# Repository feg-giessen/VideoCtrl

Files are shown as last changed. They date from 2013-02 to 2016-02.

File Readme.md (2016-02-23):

# VideoController

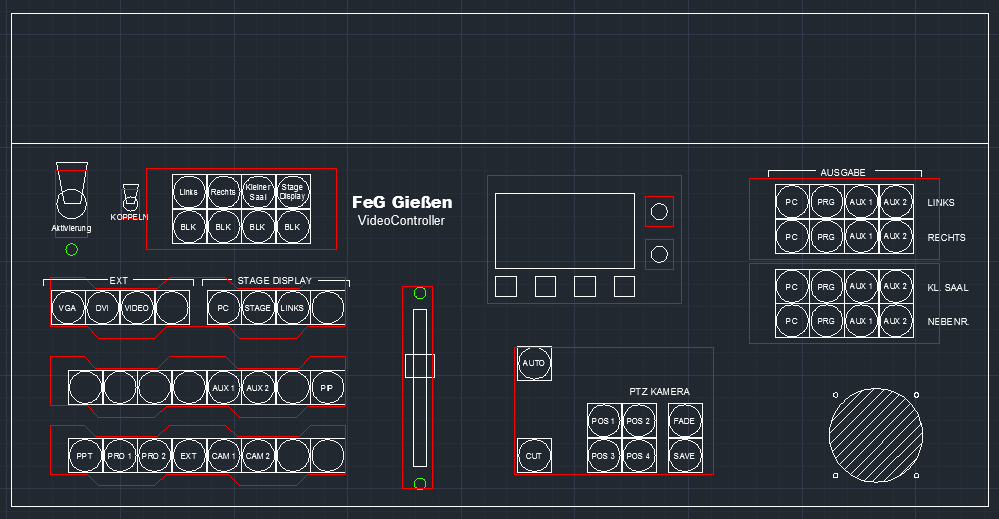
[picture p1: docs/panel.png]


Some more photos: https://www.flickr.com/photos/peschuster/tags/videoctrl/










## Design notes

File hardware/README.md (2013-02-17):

# Hardware Files #

- schematics
- part lists
- board layouts

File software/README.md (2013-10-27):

# Software Files #

- firmware
- etc.

# Development Environment 

- IDE: Eclipse Helios
- Eclipse plugins for ChibiOS: (copy to `/plugins` directory)
 - org.chibios.tools.eclipse.config_1.2.1.jar
 - org.chibios.tools.eclipse.debug_1.0.8.jar
- Compiler: arm-none-eabi (v4.7 - https://launchpad.net/gcc-arm-embedded/+download) 
- binutils (make, etc.): msys 1.0 (MinGW)

## Batch files

Start Eclipse (example):

    SET PATH=C:\Windows\system32;C:\Windows;C:\Windows\System32\Wbem;H:\Elektronik\bin-tools;H:\Elektronik\bin-tools\arm-none-eabi\bin;H:\Elektronik\MinGw\msys\1.0\bin
    
    @pushd %~dp0
    start OlimexOds\eclipse\eclipse.exe

Start OpenOCD (example):

    cd H:\Elektronik\VideoCtrl\software\firmware\VideoCtrl
    
    \Elektronik\OlimexODS\openocd-0.6.1\bin-x64\openocd-x64-0.6.1.exe -f \Elektronik\OlimexODS\openocd-0.6.1\scripts\interface\olimex-arm-usb-tiny-h.cfg -f project.cfg 

## Debug Configuration

### Init

    target remote localhost:3333
    monitor reset halt
    monitor wait_halt
    monitor sleep 100
    monitor poll
    monitor flash write_image erase build/videoctrl.bin 0x08000000
    file build/videoctrl.elf
    monitor sleep 200

### Run

    monitor soft_reset_halt
    monitor wait_halt
    monitor poll
    thbreak main
    continue

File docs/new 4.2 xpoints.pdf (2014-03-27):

name
| me | | | | me | | | | | buss | | | buss | | (DEC)
blk | 0 | 0 | 0 | 0 | 0 | 0 | 0 | 0 | 1 | 0 | 0 | 0 | 0 10 0 | 0 | 0
comp | 0 | 0 | 0 | 1 | 0 | 0 | 0 | 1 | 1 | 0 | 0 | 1 | 0 10 0 | 1 | 1
in 1 | 0 | 0 | 0 | 2 | 0 | 0 | 0 | 2 | 1 | 0 | 0 | 2 | 0 10 0 | 2 | 2
in 2 | 0 | 0 | 0 | 3 | 0 | 0 | 0 | 3 | 1 | 0 | 0 | 3 | 0 10 0 | 3 | 3
in 15 | 0 | 0 | 0 0f | 0 | 0 | 0 0f | 1 | 0 | 0 | 0f | 0 10 0 | 0f | 15
in 16 | 0 | 0 | 0 10 | 0 | 0 | 0 10 | 1 | 0 | 0 10 | 0 10 0 10 | 16
BARS | 0 | 0 | 3 e8 | 0 | 0 | 3 e8 | 1 | 0 | 3 e8 | 0 10 3 e8 | 1000
col 1 | 0 | 0 | 7 d1 | 0 | 0 | 7 d1 | 1 | 0 | 7 d1 | 0 10 7 d1 | 2001
col 2 | 0 | 0 | 7 d2 | 0 | 0 | 7 d2 | 1 | 0 | 7 d2 | 0 10 7 d2 | 2002
mp1 | 0 | 0 | b c2 | 0 | 0 | b c2 | 1 | 0 | b c2 | 0 10 b c2 | 3010
mp1K | 1 | 0 | b c3 | 0 10 b c3 | 3011
mp2 | 0 | 0 | b cc | 0 | 0 | b cc | 1 | 0 | b cc | 0 10 b cc | 3020
mp2K | 1 | 0 | b cd | 0 10 b cd | 3021
SS | 0 | 0 17 70 | 0 | 0 17 70 | 1 | 0 | 17 70 | 0 10 17 70 | 6000
Clean 1 | 1 | 0 | 1b 59 | 0 10 1b 59 | 7001
Clean 2 | 1 | 0 | 1b 5a | 0 10 1b 5a | 7002
Me1p | 1 | 0 | 27 1a | 0 10 27 1a | 10010
Me1v | 1 | 0 | 27 1b | 0 10 27 1b | 10011
me2p | 0 | 0 27 24 | 0 | 0 27 24 | 1 | 0 | 27 24 | 0 10 27 24 | 10020
me2v | 1 | 0 | 27 25 | 0 10 27 25 | 10021
| 4.2 xpoint switch and status | | 4.2 AUX xpoint switch and status
CPgI (cmd) | | PRgI (status) | | CAuS (cmd) | AuxS (status)
xpt | xpt | xpt | xpt

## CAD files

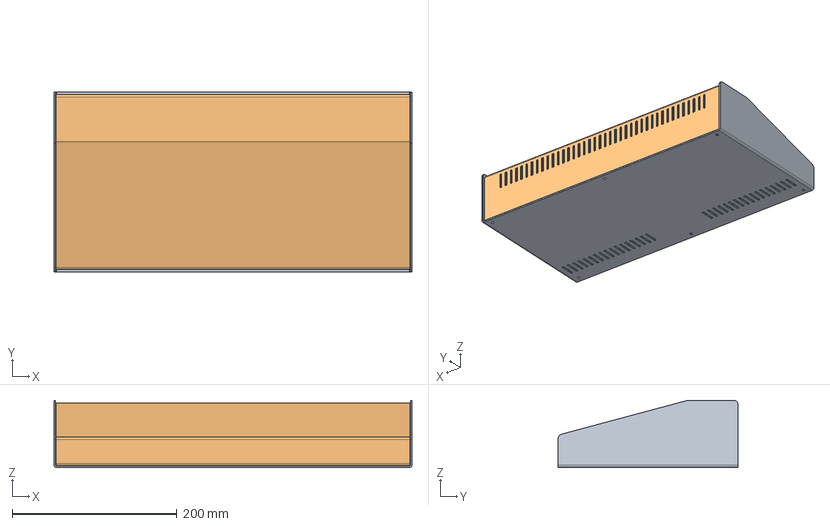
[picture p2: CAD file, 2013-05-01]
cad/1456RH3/1456RH3.stp
434.8 x 218.7 x 81.4 mm

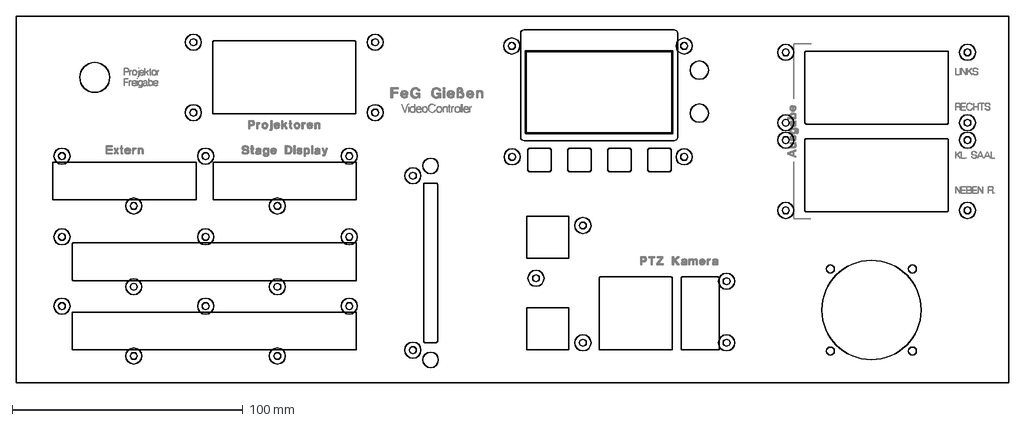
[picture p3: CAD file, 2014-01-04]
cad/enclosure/Top.dxf
430.0 x 159.0 mm

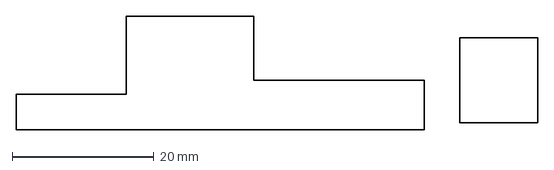
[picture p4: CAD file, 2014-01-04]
cad/enclosure/Back.dxf
73.5 x 16.0 mm

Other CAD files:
cad/Pultübersicht.dwg
cad/1456RH3/1456RH3.dwg
cad/1456RH3/1456RH3.igs

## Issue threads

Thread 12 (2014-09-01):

Lock switch for projectors

peschuster, 2014-09-01:
- [x] Wire lock switch for projectors/displays module
- [x] Implement state check in software.

peschuster, 2015-01-03:
Done.

Closed 2015-01-03.

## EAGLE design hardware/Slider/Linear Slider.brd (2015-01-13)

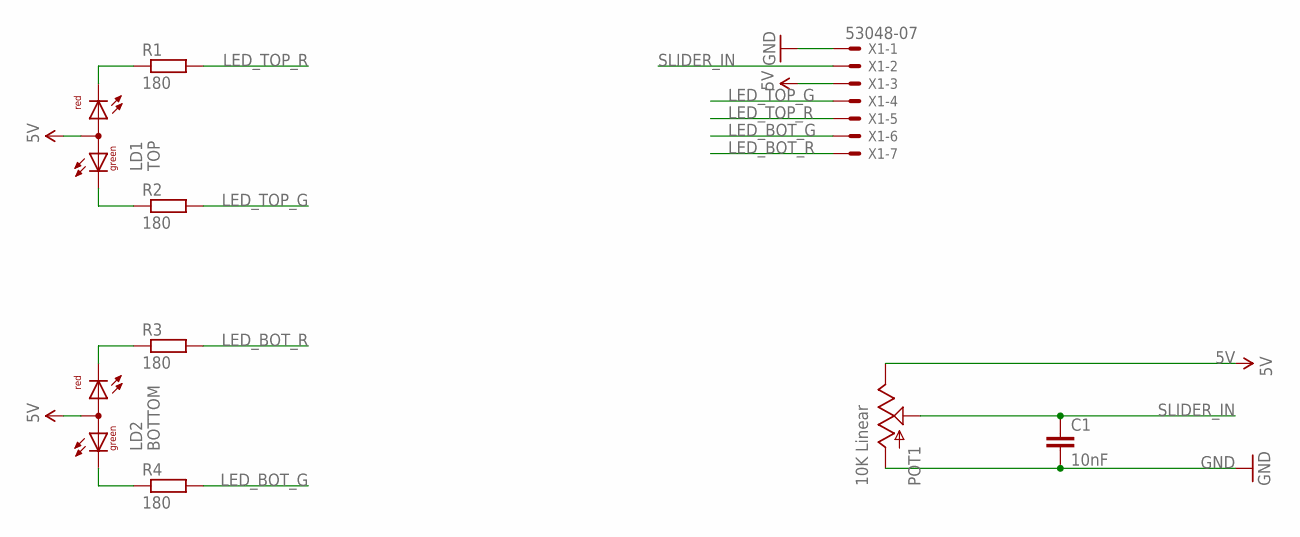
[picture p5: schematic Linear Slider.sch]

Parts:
C1: 10nF; 0603-CAP
LD1: TOP; DUOLED-A-5MM
LD2: BOTTOM; DUOLED-A-5MM
POT1: 10K Linear; SLIDER60
R1, R2, R3, R4: 180; R0603
X1: 53048-07

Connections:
5V: LD1.A, LD2.A, POT1.1 (E), X1.3
GND: C1.2, POT1.3 (A), X1.1
LED_BOT_G: R4.2, X1.6
LED_BOT_R: R3.2, X1.7
LED_TOP_G: R2.2, X1.4
LED_TOP_R: R1.2, X1.5
unnamed: LD1.CR, R1.1
unnamed: LD1.CX (CG), R2.1
unnamed: LD2.CX (CG), R4.1
unnamed: LD2.CR, R3.1
SLIDER_IN: C1.1, POT1.2A (S), X1.2

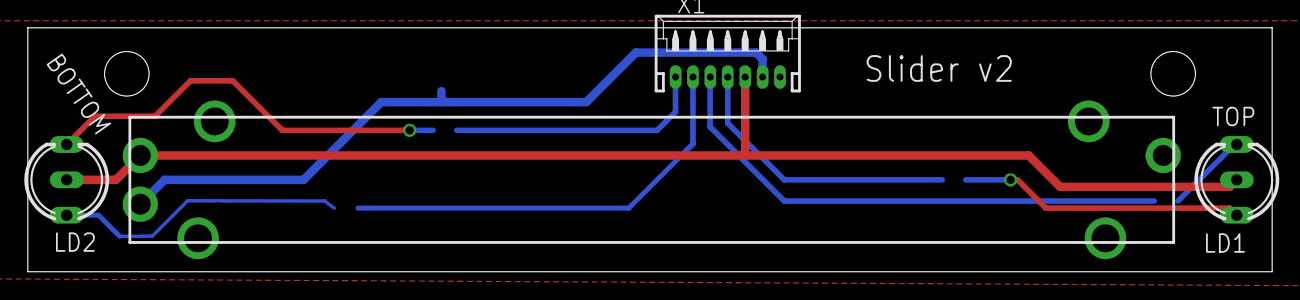
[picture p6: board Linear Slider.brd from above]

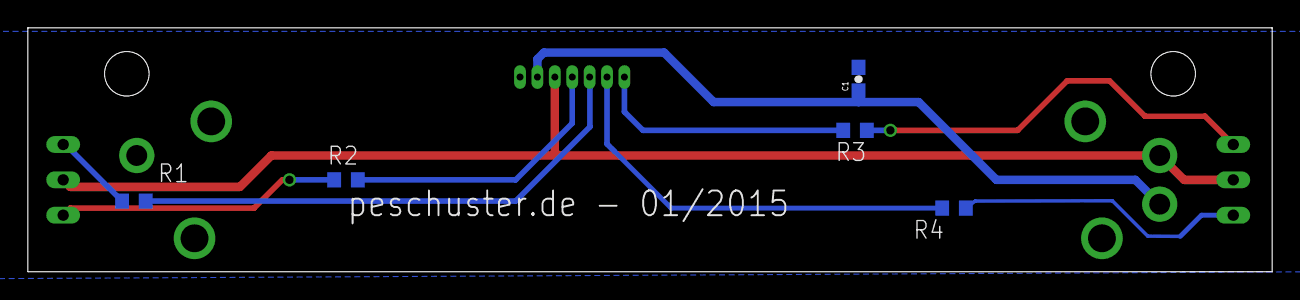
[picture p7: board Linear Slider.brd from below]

Board: 2 copper layers, 89.4 x 17.5 mm, 9 parts (5 on the bottom side), 11 nets.

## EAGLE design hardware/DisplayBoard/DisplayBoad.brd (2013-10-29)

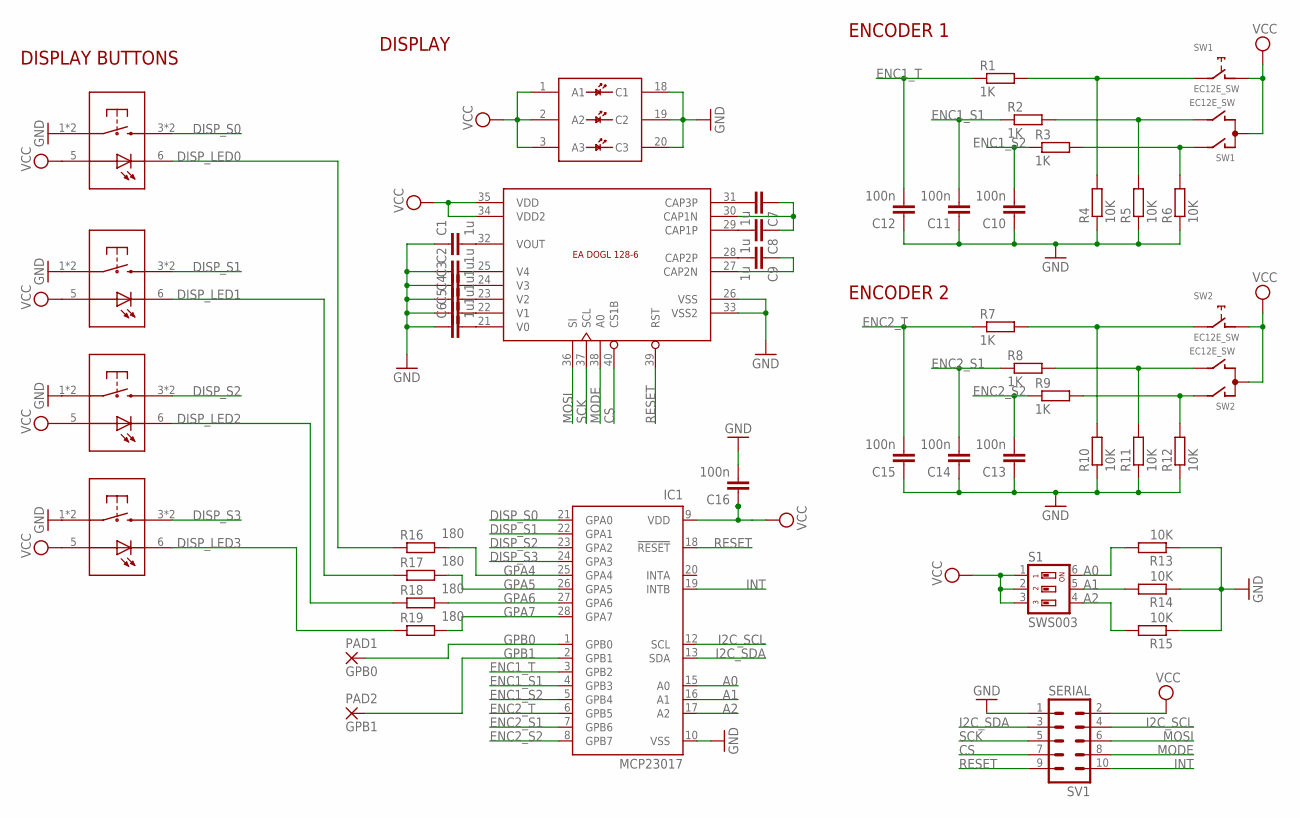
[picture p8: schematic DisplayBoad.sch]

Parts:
C1, C2, C3, C4, C5, C6, C7, C8, C9: 1u; C0805
C10, C11, C12, C13, C14, C15, C16: 100n; C0603
IC1: MCP23017; SSOP28
PAD1: GPB0; 2,15/1,0
PAD2: GPB1; 2,15/1,0
R1, R2, R3, R7, R8, R9: 1K; R0603
R4, R5, R6, R10, R11, R12, R13, R14, R15: 10K; R0603
R16, R17, R18, R19: 180; R0603
S1: SWS003; SMS-003
SV1: SERIAL; MA05-2
SW1, SW2: EC12E_SW; ALPS_EC12E_SW
U1: EADOGL128-62; EA_DOGL128-6
U$2, U$3, U$4, U$5: LP15

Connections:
A0: IC1.15 (A0), R13.2, S1.6
A1: IC1.16 (A1), R14.2, S1.5
A2: IC1.17 (A2), R15.2, S1.4
CS: SV1.7, U1.40 (CS1B)
DISP_LED0: R16.1, U$2.6
DISP_LED1: R17.1, U$3.6
DISP_LED2: R18.1, U$4.6
DISP_LED3: R19.1, U$5.6
DISP_S0: IC1.21 (GPA0), U$2.3, U$2.4 (3)
DISP_S1: IC1.22 (GPA1), U$3.3, U$3.4 (3)
DISP_S2: IC1.23 (GPA2), U$4.3, U$4.4 (3)
DISP_S3: IC1.24 (GPA3), U$5.3, U$5.4 (3)
ENC1_S1: C11.2, IC1.4 (GPB3), R2.1
ENC1_S2: C10.2, IC1.5 (GPB4), R3.1
ENC1_T: C12.2, IC1.3 (GPB2), R1.1
ENC2_S1: C14.2, IC1.7 (GPB6), R8.1
ENC2_S2: C13.2, IC1.8 (GPB7), R9.1
ENC2_T: C15.2, IC1.6 (GPB5), R7.1
GND: C1.1, C2.1, C3.1, C4.1, C5.1, C6.1, C10.1, C11.1, C12.1, C13.1, C14.1, C15.1, C16.2, IC1.10 (VSS), R4.1, R5.1, R6.1, R10.1, R11.1, R12.1, R13.1, R14.1, R15.1, SV1.1, U1.18 (C1), U1.19 (C2), U1.20 (C3), U1.26 (VSS), U1.33 (VSS2), U$2.1, U$2.2 (1), U$3.1, U$3.2 (1), U$4.1, U$4.2 (1), U$5.1, U$5.2 (1)
GPA4: IC1.25 (GPA4), R16.2
GPA5: IC1.26 (GPA5), R17.2
GPA6: IC1.27 (GPA6), R18.2
GPA7: IC1.28 (GPA7), R19.2
GPB0: IC1.1 (GPB0), PAD1.1
GPB1: IC1.2 (GPB1), PAD2.1
I2C_SCL: IC1.12 (SCL), SV1.4
I2C_SDA: IC1.13 (SDA), SV1.3
INT: IC1.19 (INTB), SV1.10
MODE: SV1.8, U1.38 (A0)
MOSI: SV1.6, U1.36 (SI)
unnamed: C1.2, U1.32 (VOUT)
unnamed: C2.2, U1.25 (V4)
unnamed: C3.2, U1.24 (V3)
unnamed: C4.2, U1.23 (V2)
unnamed: C5.2, U1.22 (V1)
unnamed: C6.2, U1.21 (V0)
unnamed: C7.2, U1.31 (CAP3P)
unnamed: C8.2, U1.29 (CAP1P)
unnamed: C9.2, U1.28 (CAP2P)
unnamed: C9.1, U1.27 (CAP2N)
unnamed: C7.1, C8.1, U1.30 (CAP1N)
unnamed: R7.2, R10.2, SW2.E (2)
unnamed: R8.2, R11.2, SW2.B
unnamed: R9.2, R12.2, SW2.A
unnamed: R1.2, R4.2, SW1.E (2)
unnamed: R2.2, R5.2, SW1.B
unnamed: R3.2, R6.2, SW1.A
RESET: IC1.18 (!RESET), SV1.9, U1.39 (RST)
SCK: SV1.5, U1.37 (SCL)
VCC: C16.1, IC1.9 (VDD), S1.1, S1.2, S1.3, SV1.2, SW1.C, SW1.D (1), SW2.C, SW2.D (1), U1.1 (A1), U1.2 (A2), U1.3 (A3), U1.34 (VDD2), U1.35 (VDD), U$2.5, U$3.5, U$4.5, U$5.5

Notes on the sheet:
ENCODER 1
ENCODER 2
DISPLAY BUTTONS
DISPLAY

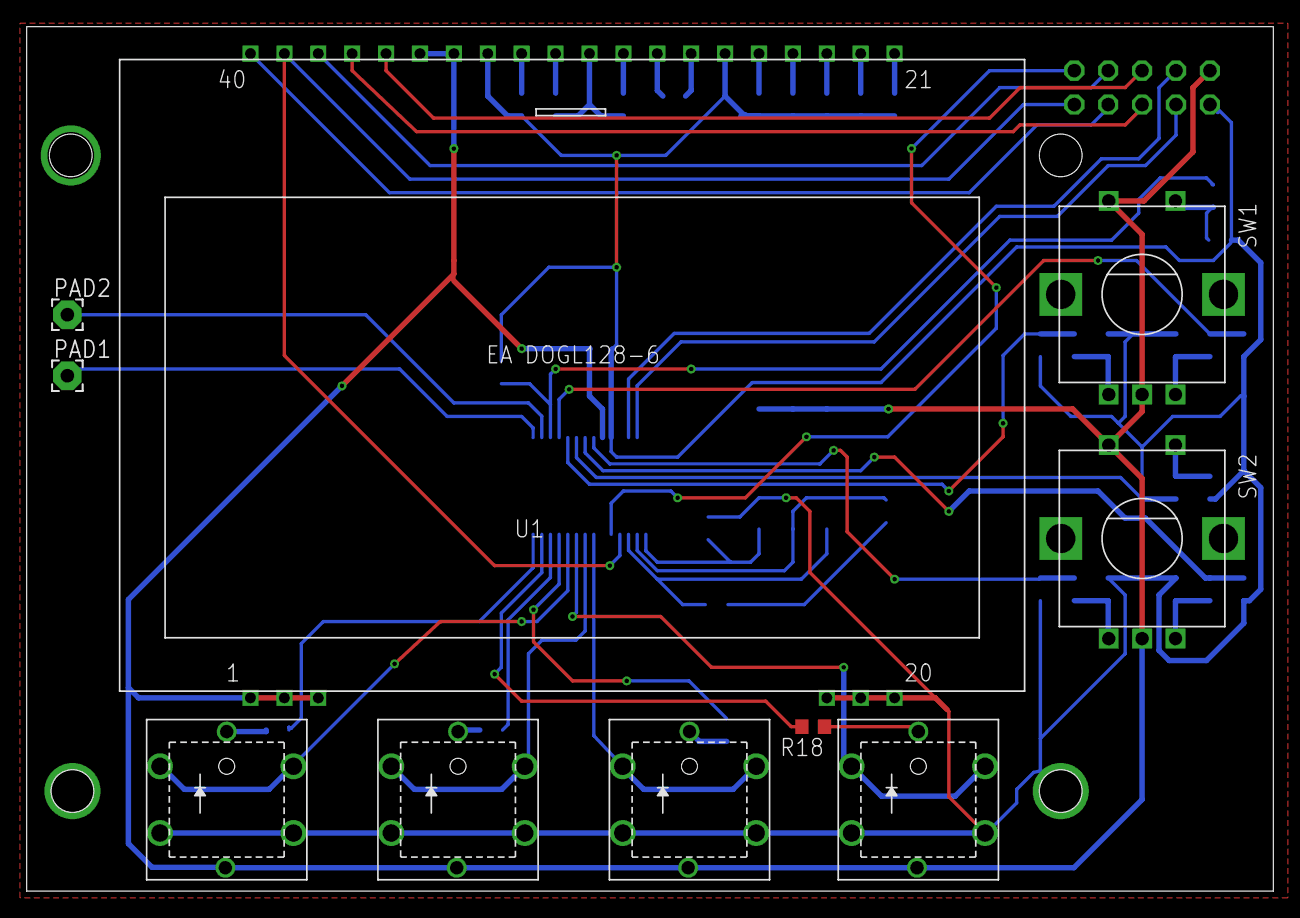
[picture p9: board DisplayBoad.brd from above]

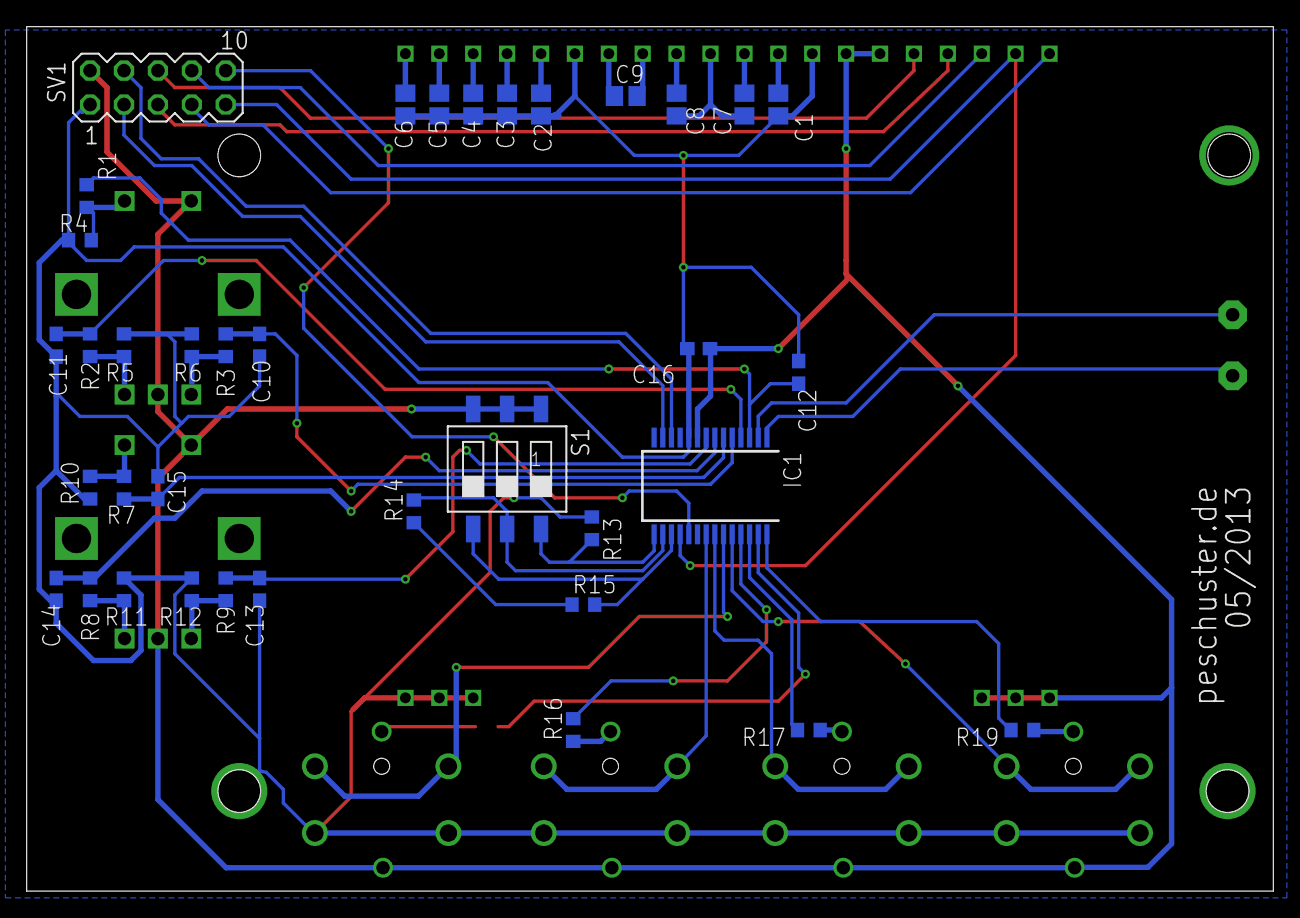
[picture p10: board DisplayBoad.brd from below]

Board: 2 copper layers, 93.4 x 64.8 mm, 47 parts (37 on the bottom side), 50 nets.

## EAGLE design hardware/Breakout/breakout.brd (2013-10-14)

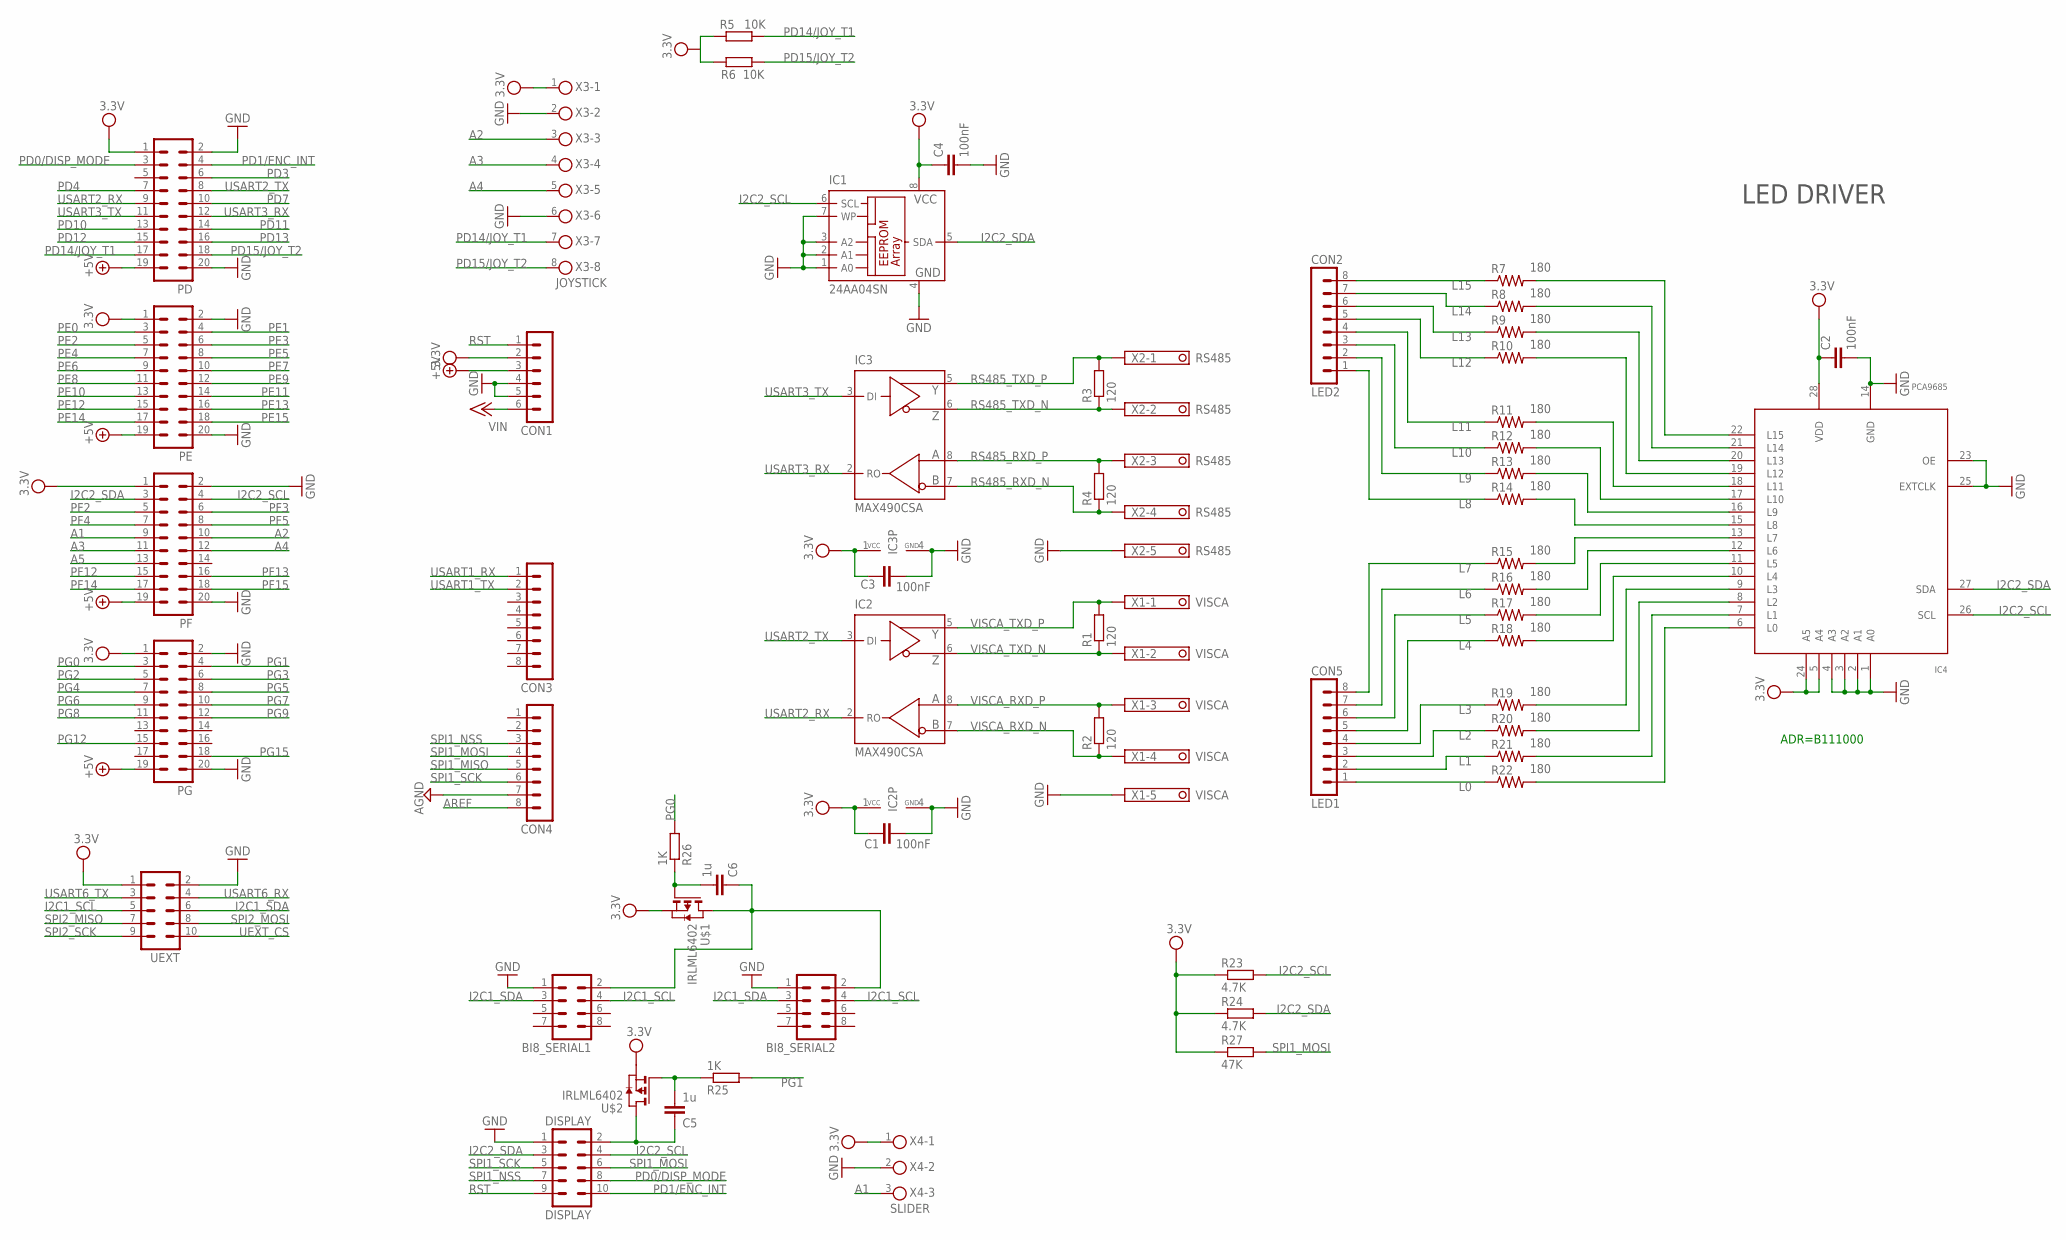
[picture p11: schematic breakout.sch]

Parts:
BI8_SERIAL1, BI8_SERIAL2: MA04-2
C1, C2, C3, C4: 100nF; 0603-CAP
C5, C6: 1u; C0805
CON1: MA06-1
CON2: LED2; MA08-1
CON3, CON4: MA08-1
CON5: LED1; MA08-1
DISPLAY: DISPLAY; MA05-2
IC1: 24AA04SN; SO-08
IC2, IC3: MAX490CSA; SO08
IC4: PCA9685; TSSOP28
PD: MA10-2
PE: MA10-2
PF: MA10-2
PG: MA10-2
R1, R2, R3, R4: 120; R0603
R5, R6: 10K; R0603
R7, R8, R9, R10, R11, R12, R13, R14, R15, R16, R17, R18, R19, R20, R21, R22: 180; 0603-RES
R23, R24: 4.7K; R0603
R25, R26: 1K; R0603
R27: 47K; R0603
U$1, U$2: IRLML6402; SOT-23
UEXT: ML10L
X1: VISCA; 1751277
X2: RS485; 1751277
X3: JOYSTICK; 8POL35
X4: SLIDER; 3POL35

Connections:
+5V: CON1.3, PD.19, PE.19, PF.19, PG.19
A1: PF.9, X4.3
A2: PF.10, X3.3
A3: PF.11, X3.4
A4: PF.12, X3.5
A5: PF.13
AGND: CON4.7
AREF: CON4.8
GND: BI8_SERIAL1.1, BI8_SERIAL2.1, C1.2, C2.2, C3.2, C4.2, CON1.4, CON1.5, DISPLAY.1, IC1.1 (A0), IC1.2 (A1), IC1.3 (A2), IC1.4 (GND), IC1.7 (WP), IC2.4 (GND), IC3.4 (GND), IC4.1 (A0), IC4.2 (A1), IC4.3 (A2), IC4.4 (A3), IC4.14 (GND), IC4.23 (OE), IC4.25 (EXTCLK), PD.2, PD.20, PE.2, PE.20, PF.2, PF.20, PG.2, PG.20, UEXT.2, X1.5, X2.5, X3.2, X3.6, X4.2
I2C1_SCL: BI8_SERIAL1.4, BI8_SERIAL2.4, UEXT.5
I2C1_SDA: BI8_SERIAL1.3, BI8_SERIAL2.3, UEXT.6
I2C2_SCL: DISPLAY.4, IC1.6 (SCL), IC4.26 (SCL), PF.4, R23.2
I2C2_SDA: DISPLAY.3, IC1.5 (SDA), IC4.27 (SDA), PF.3, R24.2
L0: CON5.1, R22.1
L1: CON5.2, R21.1
L2: CON5.3, R20.1
L3: CON5.4, R19.1
L4: CON5.5, R18.1
L5: CON5.6, R17.1
L6: CON5.7, R16.1
L7: CON5.8, R15.1
L8: CON2.1, R14.1
L9: CON2.2, R13.1
L10: CON2.3, R12.1
L11: CON2.4, R11.1
L12: CON2.5, R10.1
L13: CON2.6, R9.1
L14: CON2.7, R8.1
L15: CON2.8, R7.1
unnamed: C5.2, R25.1, U$2.1 (G)
unnamed: IC4.13 (L7), R15.2
unnamed: IC4.12 (L6), R16.2
unnamed: C6.2, R26.1, U$1.1 (G)
unnamed: IC4.11 (L5), R17.2
unnamed: BI8_SERIAL1.2, BI8_SERIAL2.2, C6.1, U$1.3 (D)
unnamed: IC4.10 (L4), R18.2
unnamed: IC4.9 (L3), R19.2
unnamed: IC4.8 (L2), R20.2
unnamed: IC4.7 (L1), R21.2
unnamed: C5.1, DISPLAY.2, U$2.3 (D)
unnamed: IC4.6 (L0), R22.2
unnamed: IC4.15 (L8), R14.2
unnamed: IC4.16 (L9), R13.2
unnamed: IC4.17 (L10), R12.2
unnamed: IC4.18 (L11), R11.2
unnamed: IC4.19 (L12), R10.2
unnamed: IC4.20 (L13), R9.2
unnamed: IC4.21 (L14), R8.2
unnamed: IC4.22 (L15), R7.2
PD0/DISP_MODE: DISPLAY.8, PD.3
PD1/ENC_INT: DISPLAY.10, PD.4
PD3: PD.6
PD4: PD.7
PD7: PD.10
PD10: PD.13
PD11: PD.14
PD12: PD.15
PD13: PD.16
PD14/JOY_T1: PD.17, R5.2, X3.7
PD15/JOY_T2: PD.18, R6.2, X3.8
PE0: PE.3
PE1: PE.4
PE2: PE.5
PE3: PE.6
PE4: PE.7
PE5: PE.8
PE6: PE.9
PE7: PE.10
PE8: PE.11
PE9: PE.12
PE10: PE.13
PE11: PE.14
PE12: PE.15
PE13: PE.16
PE14: PE.17
PE15: PE.18
PF2: PF.5
PF3: PF.6
PF4: PF.7
PF5: PF.8
PF12: PF.15
PF13: PF.16
PF14: PF.17
PF15: PF.18
PG0: PG.3, R26.2
PG1: PG.4, R25.2
PG2: PG.5
PG3: PG.6
PG4: PG.7
PG5: PG.8
PG6: PG.9
PG7: PG.10
PG8: PG.11
PG9: PG.12
PG12: PG.15
PG15: PG.18
RS485_RXD_N: IC3.7 (B), R4.1, X2.4
RS485_RXD_P: IC3.8 (A), R4.2, X2.3
RS485_TXD_N: IC3.6 (Z), R3.1, X2.2
RS485_TXD_P: IC3.5 (Y), R3.2, X2.1
RST: CON1.1, DISPLAY.9
SPI1_MISO: CON4.5
SPI1_MOSI: CON4.4, DISPLAY.6, R27.2
SPI1_NSS: CON4.3, DISPLAY.7
SPI1_SCK: CON4.6, DISPLAY.5
SPI2_MISO: UEXT.7
SPI2_MOSI: UEXT.8
SPI2_SCK: UEXT.9
UEXT_CS: UEXT.10
USART1_RX: CON3.1
USART1_TX: CON3.2
USART2_RX: IC2.2 (RO), PD.9
USART2_TX: IC2.3 (DI), PD.8
USART3_RX: IC3.2 (RO), PD.12
USART3_TX: IC3.3 (DI), PD.11
USART6_RX: UEXT.4
USART6_TX: UEXT.3
VCC: C1.1, C2.1, C3.1, C4.1, CON1.2, IC1.8 (VCC), IC2.1 (VCC), IC3.1 (VCC), IC4.5 (A4), IC4.24 (A5), IC4.28 (VDD), PD.1, PE.1, PF.1, PG.1, R5.1, R6.1, R23.1, R24.1, R27.1, U$1.2 (S), U$2.2 (S), UEXT.1, X3.1, X4.1
VIN: CON1.6
VISCA_RXD_N: IC2.7 (B), R2.1, X1.4
VISCA_RXD_P: IC2.8 (A), R2.2, X1.3
VISCA_TXD_N: IC2.6 (Z), R1.1, X1.2
VISCA_TXD_P: IC2.5 (Y), R1.2, X1.1

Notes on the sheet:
ADR=B111000
LED DRIVER

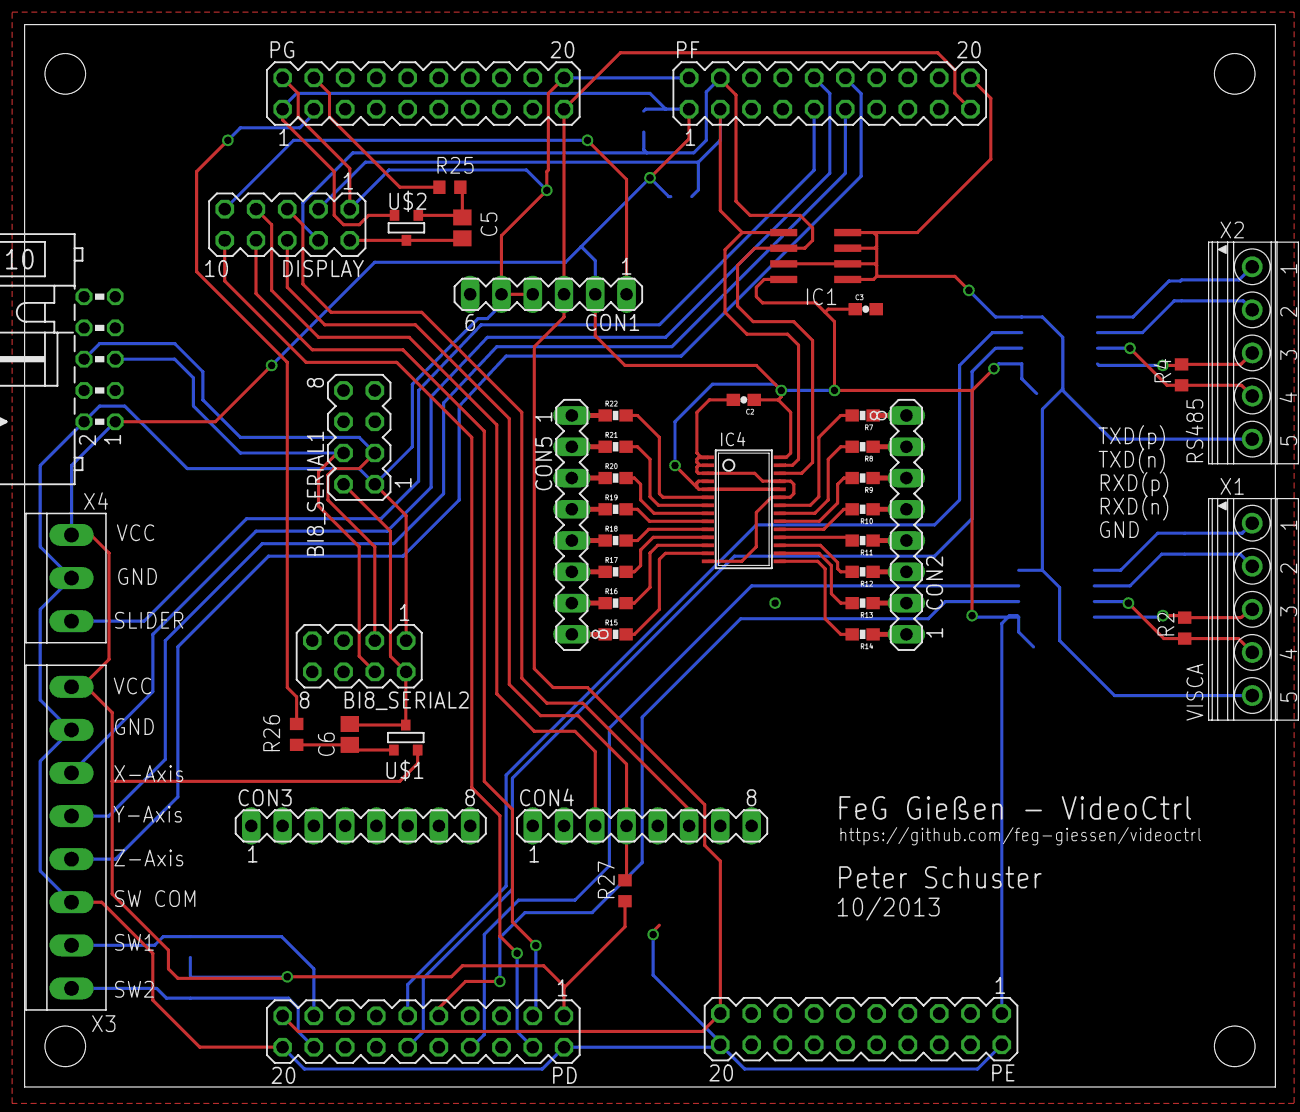
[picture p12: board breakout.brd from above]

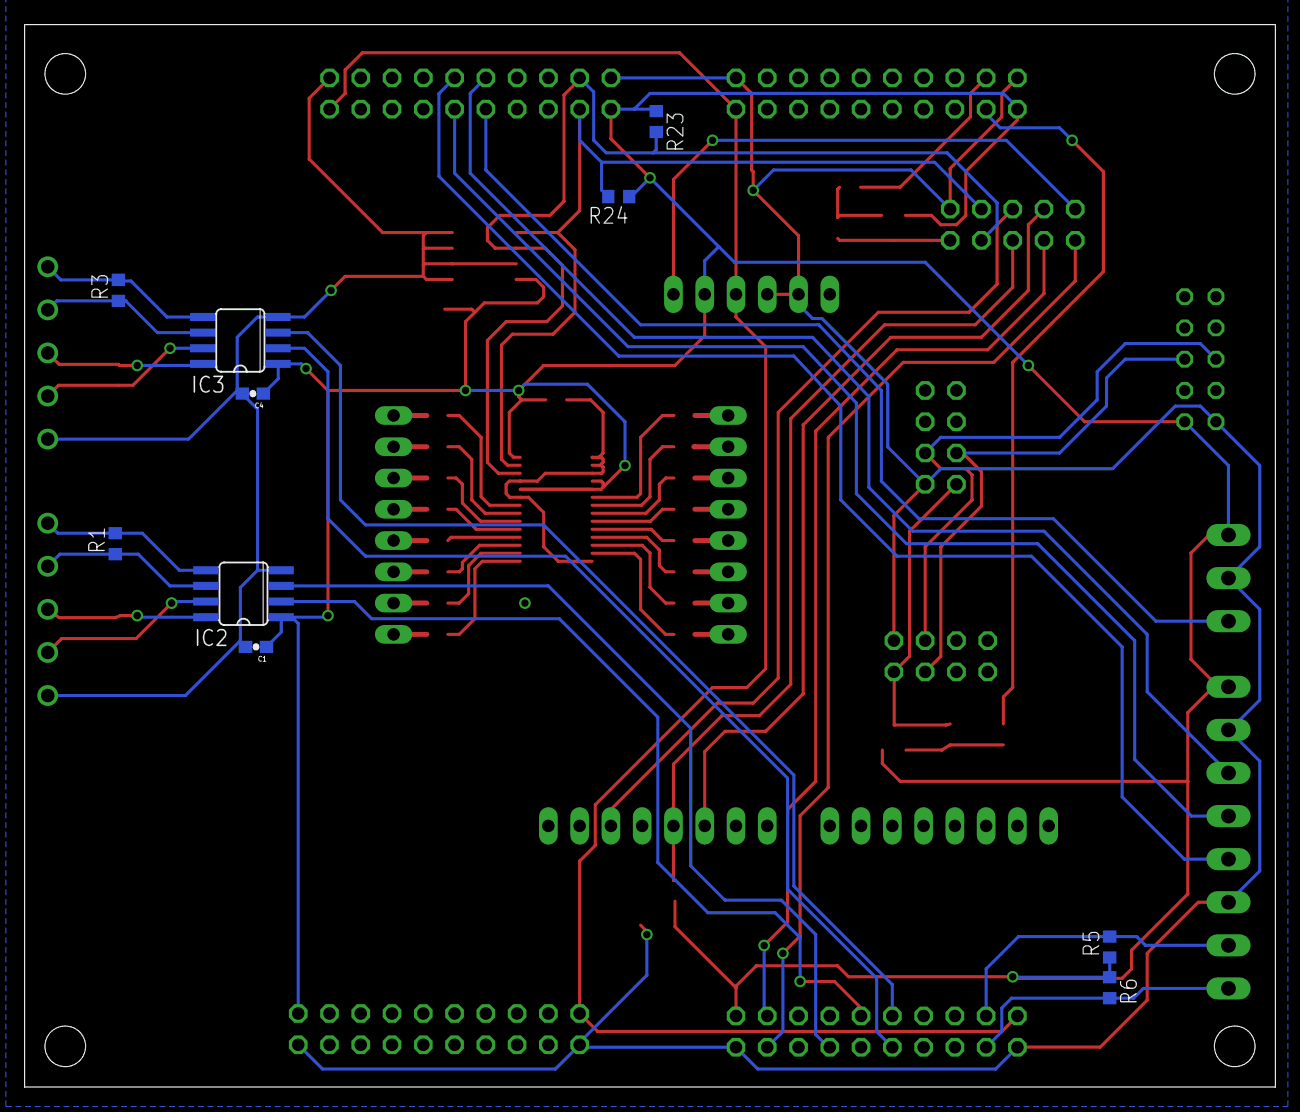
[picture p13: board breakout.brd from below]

Board: 2 copper layers, 101.6 x 86.3 mm, 56 parts (10 on the bottom side), 69 nets.

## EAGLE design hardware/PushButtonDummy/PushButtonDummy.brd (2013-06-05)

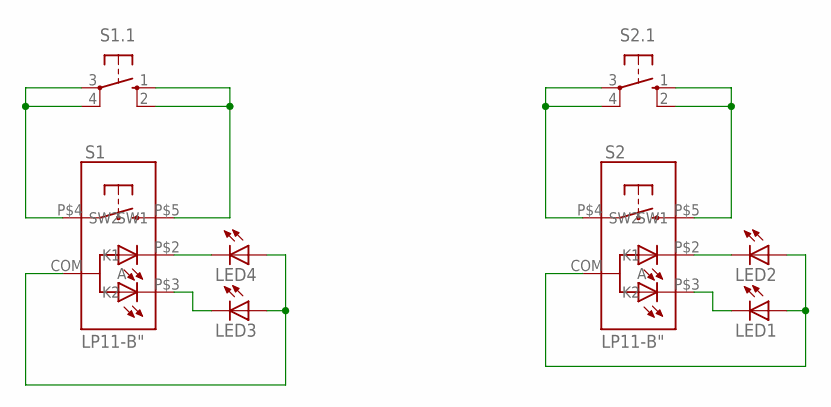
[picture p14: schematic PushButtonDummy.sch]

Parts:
LED1, LED2, LED3, LED4: LED3MM
S1, S2: LP11-B"; LP11
S1.1, S2.1: 10-XX; B3F-10XX

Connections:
unnamed: S1.P$4 (SW1), S1.1.3, S1.1.4 (P1)
unnamed: S1.P$5 (SW2), S1.1.1 (S), S1.1.2 (S1)
unnamed: S2.P$5 (SW2), S2.1.1 (S), S2.1.2 (S1)
unnamed: S2.P$4 (SW1), S2.1.3, S2.1.4 (P1)
unnamed: LED4.K (C), S1.P$2 (K1)
unnamed: LED3.K (C), S1.P$3 (K2)
unnamed: LED2.K (C), S2.P$2 (K1)
unnamed: LED1.K (C), S2.P$3 (K2)
unnamed: LED1.A, LED2.A, S2.COM (A)
unnamed: LED3.A, LED4.A, S1.COM (A)

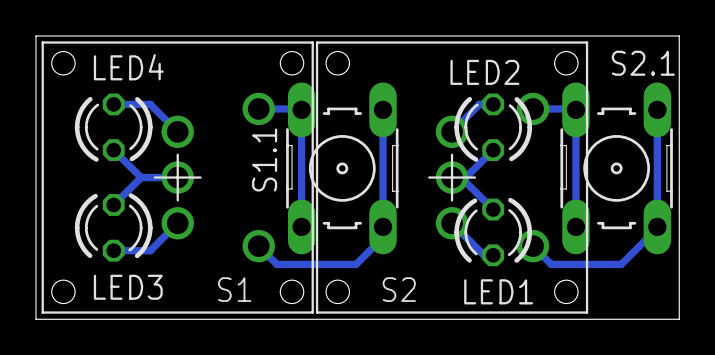
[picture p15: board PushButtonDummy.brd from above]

Board: 2 copper layers, 35.7 x 15.7 mm, 8 parts (0 on the bottom side), 10 nets.

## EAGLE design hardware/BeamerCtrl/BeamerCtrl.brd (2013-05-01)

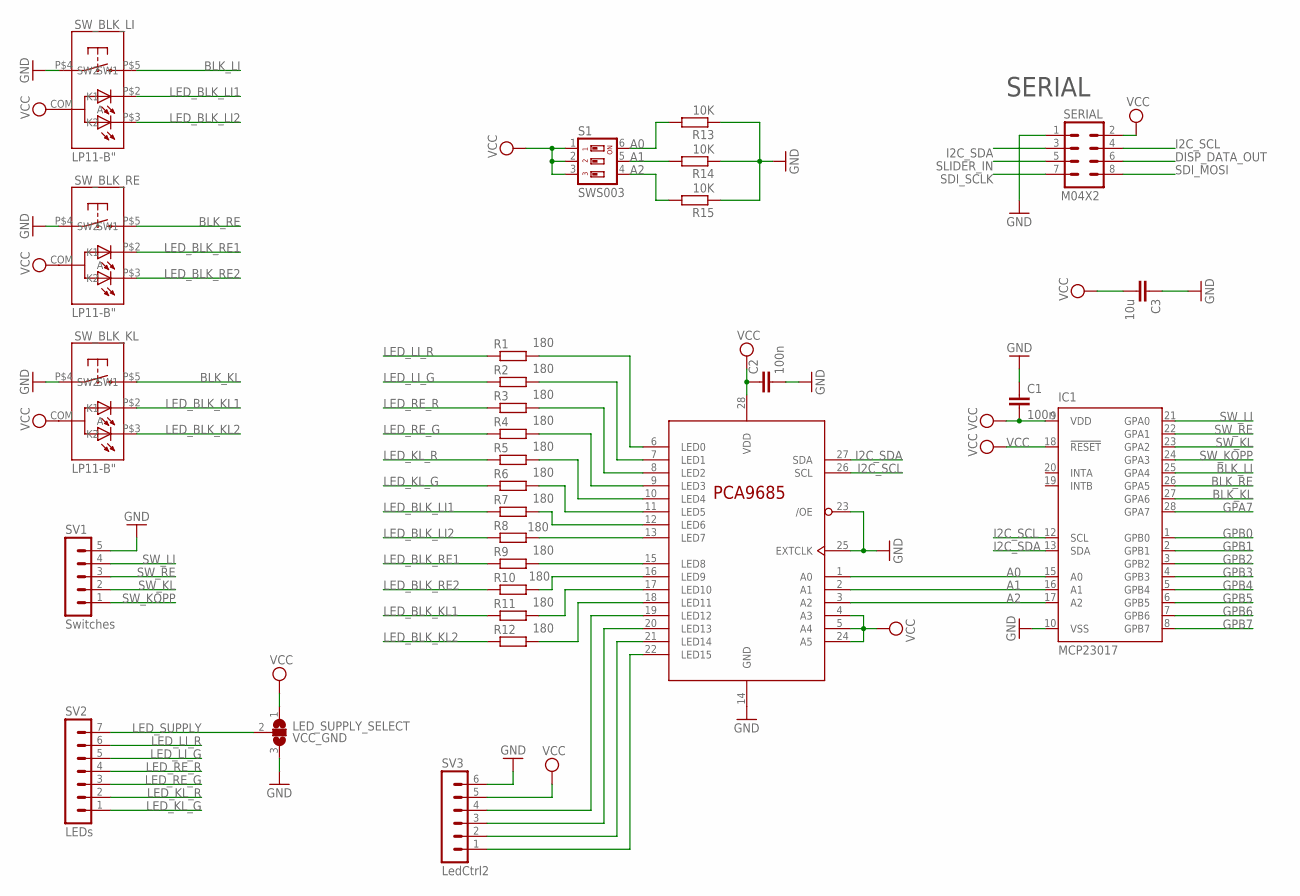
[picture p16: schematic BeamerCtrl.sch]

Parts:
C1, C2: 100n; C0603
C3: 10u; C0805
IC1: MCP23017; SSOP28
IC2: PCA9685PW; TSSOP28
LED_SUPPLY_SELECT: VCC_GND; SJ_2
R1, R2, R3, R4, R5, R6, R7, R8, R9, R10, R11, R12: 180; R0603
R13, R14, R15: 10K; R0603
S1: SWS003; SMS-003
SERIAL: M04X2; 2X4
SV1: Switches; MA05-1
SV2: LEDs; MA07-1
SV3: LedCtrl2; MA06-1
SW_BLK_KL: LP11-B"; LP11
SW_BLK_LI: LP11-B"; LP11
SW_BLK_RE: LP11-B"; LP11

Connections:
A0: IC1.15 (A0), IC2.1 (A0), R13.2, S1.6
A1: IC1.16 (A1), IC2.2 (A1), R14.2, S1.5
A2: IC1.17 (A2), IC2.3 (A2), R15.2, S1.4
BLK_KL: IC1.27 (GPA6), SW_BLK_KL.P$5 (SW2)
BLK_LI: IC1.25 (GPA4), SW_BLK_LI.P$5 (SW2)
BLK_RE: IC1.26 (GPA5), SW_BLK_RE.P$5 (SW2)
DISP_DATA_OUT: SERIAL.6
GND: C1.1, C2.2, C3.1, IC1.10 (VSS), IC2.14 (GND), IC2.23 (/OE), IC2.25 (EXTCLK), LED_SUPPLY_SELECT.3, R13.1, R14.1, R15.1, SERIAL.1, SV1.5, SV3.6, SW_BLK_KL.P$4 (SW1), SW_BLK_LI.P$4 (SW1), SW_BLK_RE.P$4 (SW1)
GPA7: IC1.28 (GPA7)
GPB0: IC1.1 (GPB0)
GPB1: IC1.2 (GPB1)
GPB2: IC1.3 (GPB2)
GPB3: IC1.4 (GPB3)
GPB4: IC1.5 (GPB4)
GPB5: IC1.6 (GPB5)
GPB6: IC1.7 (GPB6)
GPB7: IC1.8 (GPB7)
I2C_SCL: IC1.12 (SCL), IC2.26 (SCL), SERIAL.4
I2C_SDA: IC1.13 (SDA), IC2.27 (SDA), SERIAL.3
LED_BLK_KL1: R11.1, SW_BLK_KL.P$2 (K1)
LED_BLK_KL2: R12.1, SW_BLK_KL.P$3 (K2)
LED_BLK_LI1: R7.1, SW_BLK_LI.P$2 (K1)
LED_BLK_LI2: R8.1, SW_BLK_LI.P$3 (K2)
LED_BLK_RE1: R9.1, SW_BLK_RE.P$2 (K1)
LED_BLK_RE2: R10.1, SW_BLK_RE.P$3 (K2)
LED_KL_G: R6.1, SV2.1
LED_KL_R: R5.1, SV2.2
LED_LI_G: R2.1, SV2.5
LED_LI_R: R1.1, SV2.6
LED_RE_G: R4.1, SV2.3
LED_RE_R: R3.1, SV2.4
LED_SUPPLY: LED_SUPPLY_SELECT.2, SV2.7
unnamed: IC2.19 (LED12), SV3.4
unnamed: IC2.20 (LED13), SV3.3
unnamed: IC2.21 (LED14), SV3.2
unnamed: IC2.22 (LED15), SV3.1
unnamed: IC2.6 (LED0), R1.2
unnamed: IC2.7 (LED1), R2.2
unnamed: IC2.8 (LED2), R3.2
unnamed: IC2.9 (LED3), R4.2
unnamed: IC2.10 (LED4), R5.2
unnamed: IC2.11 (LED5), R6.2
unnamed: IC2.12 (LED6), R7.2
unnamed: IC2.13 (LED7), R8.2
unnamed: IC2.15 (LED8), R9.2
unnamed: IC2.16 (LED9), R10.2
unnamed: IC2.17 (LED10), R11.2
unnamed: IC2.18 (LED11), R12.2
SDI_MOSI: SERIAL.8
SDI_SCLK: SERIAL.7
SLIDER_IN: SERIAL.5
SW_KL: IC1.23 (GPA2), SV1.2
SW_KOPP: IC1.24 (GPA3), SV1.1
SW_LI: IC1.21 (GPA0), SV1.4
SW_RE: IC1.22 (GPA1), SV1.3
VCC: C1.2, C2.1, C3.2, IC1.9 (VDD), IC1.18 (!RESET), IC2.4 (A3), IC2.5 (A4), IC2.24 (A5), IC2.28 (VDD), LED_SUPPLY_SELECT.1, S1.1, S1.2, S1.3, SERIAL.2, SV3.5, SW_BLK_KL.COM (A), SW_BLK_LI.COM (A), SW_BLK_RE.COM (A)

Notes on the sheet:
SERIAL



Board: 2 copper layers, 43.6 x 50.0 mm, 29 parts (12 on the bottom side), 43 nets.

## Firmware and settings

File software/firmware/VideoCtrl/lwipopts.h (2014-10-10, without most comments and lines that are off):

#define __LWIPOPTS_H__
#define SYS_LIGHTWEIGHT_PROT            0
#define NO_SYS                          0
#define NO_SYS_NO_TIMERS                0
#define MEMCPY(dst,src,len)             memcpy(dst,src,len)
#define SMEMCPY(dst,src,len)            memcpy(dst,src,len)
#define MEM_LIBC_MALLOC                 0
#define MEMP_MEM_MALLOC                 0
#define MEM_ALIGNMENT                   4
#define MEM_SIZE                        1600
#define MEMP_SEPARATE_POOLS             0
#define MEMP_OVERFLOW_CHECK             0
#define MEMP_SANITY_CHECK               0
#define MEM_USE_POOLS                   0
#define MEM_USE_POOLS_TRY_BIGGER_POOL   0
#define MEMP_USE_CUSTOM_POOLS           0
#define LWIP_ALLOW_MEM_FREE_FROM_OTHER_CONTEXT 0
#define MEMP_NUM_PBUF                   16
#define MEMP_NUM_RAW_PCB                4
#define MEMP_NUM_UDP_PCB                4
#define MEMP_NUM_TCP_PCB                10
#define MEMP_NUM_TCP_PCB_LISTEN         8
#define MEMP_NUM_TCP_SEG                16
#define MEMP_NUM_REASSDATA              5
#define MEMP_NUM_FRAG_PBUF              15
#define MEMP_NUM_ARP_QUEUE              30
#define MEMP_NUM_IGMP_GROUP             8
#define MEMP_NUM_SYS_TIMEOUT            (LWIP_TCP + IP_REASSEMBLY + LWIP_ARP + (2*LWIP_DHCP) + LWIP_AUTOIP + LWIP_IGMP + LWIP_DNS + PPP_SUPPORT)
#define MEMP_NUM_NETBUF                 2
#define MEMP_NUM_NETCONN                4
#define MEMP_NUM_TCPIP_MSG_API          8
#define MEMP_NUM_TCPIP_MSG_INPKT        8
#define MEMP_NUM_SNMP_NODE              50
#define MEMP_NUM_SNMP_ROOTNODE          30
#define MEMP_NUM_SNMP_VARBIND           2
#define MEMP_NUM_SNMP_VALUE             3
#define MEMP_NUM_NETDB                  1
#define MEMP_NUM_LOCALHOSTLIST          1
#define MEMP_NUM_PPPOE_INTERFACES       1
#define PBUF_POOL_SIZE                  16
#define LWIP_ARP                        1
#define ARP_TABLE_SIZE                  10
#define ARP_QUEUEING                    0
#define ETHARP_TRUST_IP_MAC             0
#define ETHARP_SUPPORT_VLAN             0
#define LWIP_ETHERNET                   (LWIP_ARP || PPPOE_SUPPORT)
#define ETH_PAD_SIZE                    0
#define ETHARP_SUPPORT_STATIC_ENTRIES   0
#define IP_FORWARD                      0
#define IP_OPTIONS_ALLOWED              1
#define IP_REASSEMBLY                   1
#define IP_FRAG                         1
#define IP_REASS_MAXAGE                 3
#define IP_REASS_MAX_PBUFS              10
#define IP_FRAG_USES_STATIC_BUF         0
#if IP_FRAG_USES_STATIC_BUF && !defined(IP_FRAG_MAX_MTU)
#define IP_FRAG_MAX_MTU                 1500
#endif
#define IP_DEFAULT_TTL                  255
#define IP_SOF_BROADCAST                0
#define IP_SOF_BROADCAST_RECV           0
#define IP_FORWARD_ALLOW_TX_ON_RX_NETIF 0
#define LWIP_RANDOMIZE_INITIAL_LOCAL_PORTS 0
#define LWIP_ICMP                       1
#define ICMP_TTL                       (IP_DEFAULT_TTL)
#define LWIP_BROADCAST_PING             0
#define LWIP_MULTICAST_PING             0
#define LWIP_RAW                        1
#define RAW_TTL                        (IP_DEFAULT_TTL)
#define LWIP_DHCP                       0
#define DHCP_DOES_ARP_CHECK             ((LWIP_DHCP) && (LWIP_ARP))
#define LWIP_AUTOIP                     0
#define LWIP_DHCP_AUTOIP_COOP           0
#define LWIP_DHCP_AUTOIP_COOP_TRIES     9
#define LWIP_SNMP                       0
#define SNMP_CONCURRENT_REQUESTS        1
#define SNMP_TRAP_DESTINATIONS          1
#define SNMP_PRIVATE_MIB                0
#define SNMP_SAFE_REQUESTS              1
#define SNMP_MAX_OCTET_STRING_LEN       127
#define SNMP_MAX_TREE_DEPTH             15
#define SNMP_MAX_VALUE_SIZE             LWIP_MAX((SNMP_MAX_OCTET_STRING_LEN)+1, sizeof(s32_t)*(SNMP_MAX_TREE_DEPTH))
#define LWIP_IGMP                       0
#define LWIP_DNS                        0
#define DNS_TABLE_SIZE                  4
#define DNS_MAX_NAME_LENGTH             256
#define DNS_MAX_SERVERS                 2
#define DNS_DOES_NAME_CHECK             1
#define DNS_MSG_SIZE                    512
#define DNS_LOCAL_HOSTLIST              0
#define DNS_LOCAL_HOSTLIST_IS_DYNAMIC   0
#define LWIP_UDP                        1
#define LWIP_UDPLITE                    0
#define UDP_TTL                         (IP_DEFAULT_TTL)
#define LWIP_NETBUF_RECVINFO            0
#define LWIP_TCP                        1
#define TCP_TTL                         (IP_DEFAULT_TTL)
#define TCP_WND                         (4 * TCP_MSS)
#define TCP_MAXRTX                      12
#define TCP_SYNMAXRTX                   6
#define TCP_QUEUE_OOSEQ                 (LWIP_TCP)
#define TCP_MSS                         536
#define TCP_CALCULATE_EFF_SEND_MSS      1
#define TCP_SND_BUF                     (2 * TCP_MSS)
#define TCP_SND_QUEUELEN                ((4 * (TCP_SND_BUF) + (TCP_MSS - 1))/(TCP_MSS))
#define TCP_SNDLOWAT                    LWIP_MIN(LWIP_MAX(((TCP_SND_BUF)/2), (2 * TCP_MSS) + 1), (TCP_SND_BUF) - 1)
#define TCP_SNDQUEUELOWAT               LWIP_MAX(((TCP_SND_QUEUELEN)/2), 5)
#define TCP_OOSEQ_MAX_BYTES             0
#define TCP_OOSEQ_MAX_PBUFS             0
#define TCP_LISTEN_BACKLOG              0
#define TCP_DEFAULT_LISTEN_BACKLOG      0xff
#define TCP_OVERSIZE                    TCP_MSS
#define LWIP_TCP_TIMESTAMPS             0
#define TCP_WND_UPDATE_THRESHOLD   (TCP_WND / 4)
#if !defined(LWIP_EVENT_API) && !defined(LWIP_CALLBACK_API)
#define LWIP_EVENT_API                  0
#define LWIP_CALLBACK_API               1
#endif
#define PBUF_LINK_HLEN                  (14 + ETH_PAD_SIZE)
#define PBUF_POOL_BUFSIZE               LWIP_MEM_ALIGN_SIZE(TCP_MSS+40+PBUF_LINK_HLEN)
#define LWIP_NETIF_HOSTNAME             0
#define LWIP_NETIF_API                  0
#define LWIP_NETIF_STATUS_CALLBACK      0
#define LWIP_NETIF_LINK_CALLBACK        0
#define LWIP_NETIF_REMOVE_CALLBACK      0
#define LWIP_NETIF_HWADDRHINT           0
#define LWIP_NETIF_LOOPBACK             0
#define LWIP_LOOPBACK_MAX_PBUFS         0
#define LWIP_NETIF_LOOPBACK_MULTITHREADING    (!NO_SYS)
#define LWIP_NETIF_TX_SINGLE_PBUF             0
#define LWIP_HAVE_LOOPIF                0
#define LWIP_HAVE_SLIPIF                0
#define TCPIP_THREAD_NAME              "tcpip_thread"
#define TCPIP_THREAD_STACKSIZE          1024
#define TCPIP_THREAD_PRIO               (LOWPRIO + 1)
#define TCPIP_MBOX_SIZE                 MEMP_NUM_PBUF
#define SLIPIF_THREAD_NAME             "slipif_loop"
#define SLIPIF_THREAD_STACKSIZE         1024
#define SLIPIF_THREAD_PRIO              (LOWPRIO + 1)
#define PPP_THREAD_NAME                "pppInputThread"
#define PPP_THREAD_STACKSIZE            1024
#define PPP_THREAD_PRIO                 (LOWPRIO + 1)
#define DEFAULT_THREAD_NAME            "lwIP"
#define DEFAULT_THREAD_STACKSIZE        1024
#define DEFAULT_THREAD_PRIO             (LOWPRIO + 1)
#define DEFAULT_RAW_RECVMBOX_SIZE       4
#define DEFAULT_UDP_RECVMBOX_SIZE       4
#define DEFAULT_TCP_RECVMBOX_SIZE       40
#define DEFAULT_ACCEPTMBOX_SIZE         4
#define LWIP_TCPIP_CORE_LOCKING         0
#define LWIP_TCPIP_CORE_LOCKING_INPUT   0
#define LWIP_NETCONN                    1
#define LWIP_TCPIP_TIMEOUT              1
#define LWIP_SOCKET                     1
#define LWIP_COMPAT_SOCKETS             1
#define LWIP_POSIX_SOCKETS_IO_NAMES     1
#define LWIP_TCP_KEEPALIVE              0
#define LWIP_SO_SNDTIMEO                0
#define LWIP_SO_RCVTIMEO                1
#define LWIP_SO_RCVBUF                  0
#define RECV_BUFSIZE_DEFAULT            INT_MAX
#define SO_REUSE                        0
#define SO_REUSE_RXTOALL                0
#define LWIP_STATS                      1
#if LWIP_STATS
#define LWIP_STATS_DISPLAY              0
#define LINK_STATS                      1
#define ETHARP_STATS                    (LWIP_ARP)
#define IP_STATS                        1
#define IPFRAG_STATS                    (IP_REASSEMBLY || IP_FRAG)
#define ICMP_STATS                      1
#define IGMP_STATS                      (LWIP_IGMP)
#define UDP_STATS                       (LWIP_UDP)
#define TCP_STATS                       (LWIP_TCP)
#define MEM_STATS                       ((MEM_LIBC_MALLOC == 0) && (MEM_USE_POOLS == 0))
#define MEMP_STATS                      (MEMP_MEM_MALLOC == 0)
#define SYS_STATS                       (NO_SYS == 0)
#else
#define LINK_STATS                      0
#define IP_STATS                        0
#define IPFRAG_STATS                    0
#define ICMP_STATS                      0
#define IGMP_STATS                      0
#define UDP_STATS                       0
#define TCP_STATS                       0
#define MEM_STATS                       0
#define MEMP_STATS                      0
#define SYS_STATS                       0
#define LWIP_STATS_DISPLAY              0
#endif
#define PPP_SUPPORT                     0
#define PPPOE_SUPPORT                   0
#define PPPOS_SUPPORT                   PPP_SUPPORT
#if PPP_SUPPORT
#define NUM_PPP                         1
#define PAP_SUPPORT                     0
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

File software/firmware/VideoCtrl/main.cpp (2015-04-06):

#include <string.h>
#include <stdio.h>
#include "ch.h"
#include "ch.hpp"
#include "hal.h"
#include "halconf.h"
#include "chconf.h"
#include "board_hw.h"
#include "lwip/init.h"
#include "lwipthread.h"
#include "lwip/ip_addr.h"
#include "net/web/WebServer.h"
#include "lib/MatrixSwitch.h"
#include "lib/ATEM.h"
#include "lib/hw/PCA9685.h"
#include "lib/SkaarhojBI8.h"
#include "lib/Display.h"
#include "app/ReaderThread.h"
#include "app/HwModules.h"
#include "app/Memory.h"
#include "app/Videoswitcher.h"
#include "app/VideoMatrix.h"
#include "app/ButtonMapper.h"
#include "app/OutputDisplays.h"
#include "app/ScalerAndSwitchModule.h"
#include "app/PtzCamera.h"
#include "lib/AdcChannel.h"

#include "lib/menu/MenuController.h"
#include "app/menu/HomeScreen.h"

// ----- ----- ----- ----- ----- ----- ----- ----- ----- -----

static bool blink_enable;

static Videoswitcher* s_atem;
static OutputDisplays* s_displays;
static PtzCamera* s_camera;
static MenuController* s_menu;

static MenuController menu;

static WebServer webServerThread;
static ReaderThread readerThread;
static HwModules hwModules;
static Memory memory;
static adcsample_t adc_buffer[ADC3_CH_NUM * ADC3_SMP_DEPTH];

Videoswitcher atem;
ButtonMapper mapper;
VideoMatrix matrix;
PtzCamera camera;
AdcChannel channelX;
AdcChannel channelY;
AdcChannel channelZ;
AdcChannel channelFader;
OutputDisplays displays;
ScalerAndSwitchModule scalerAndSwitch;

HomeScreen menu_home;

// netif options
struct lwipthread_opts net_opts;

// ----- ----- ----- ----- ----- ----- ----- ----- ----- -----
// LED blinker thread, times are in milliseconds.

static WORKING_AREA(waBlinkThread, 256);
static msg_t BlinkThread(void *arg) {
    (void)arg;
    chRegSetThreadName("blinker");
    while (TRUE) {
        palClearPad(GPIOC, GPIOC_LED);
        if (s_menu != NULL)
            s_menu->liveToggle();
        if (s_atem != NULL && blink_enable)
            s_atem->doBlink();
        if (s_displays != NULL && blink_enable)
            s_displays->doBlink();

        chThdSleepMilliseconds(300);

        palSetPad(GPIOC, GPIOC_LED);
        if (s_atem != NULL && blink_enable)
            s_atem->doBlink();
        if (s_displays != NULL && blink_enable)
            s_displays->doBlink();

        chThdSleepMilliseconds(300);
    }
    return 0;
}

static WORKING_AREA(waTimeCriticalThread, 1024);
static msg_t TimeCriticalThread(void *arg) {
    (void)arg;
    chRegSetThreadName("atem");
    while (TRUE) {

        if (s_atem != NULL) {
            s_atem->run();
        }
        if (s_camera != NULL) {
            s_camera->run();
        }

        chThdSleepMilliseconds(1);
    }
    return 0;
}

// ----- ----- ----- ----- ----- ----- ----- ----- ----- -----
// Application entry point.

int main(void) {

    //
    // Static pointers for blink thread

    blink_enable = false;

    s_atem = NULL;
    s_menu = NULL;
    s_displays = &displays;
    s_camera = &camera;

    /*
    * System initializations.
    * - HAL initialization, this also initializes the configured device drivers
    *   and performs the board-specific initializations.
    * - Kernel initialization, the main() function becomes a thread and the
    *   RTOS is active.
    */
    halInit();
    chibios_rt::System::init();
    init_board_hal();

    // create alive blinker
    chThdCreateStatic(waBlinkThread, sizeof(waBlinkThread), NORMALPRIO, BlinkThread, NULL);

    chThdSleepMilliseconds(500);

    hwModules.init();

    char build_timestamp[19];
    memcpy(build_timestamp, __DATE__, 12);
    build_timestamp[12] = ' ';
    memcpy(&build_timestamp[13], __TIME__, 6);
    build_timestamp[18] = '\0';

    menu_home.setBuildTimestamp(build_timestamp);
    menu_home.setText(0, (char*)"Stat.");
    menu_home.setText(1, (char*)"Butt.");
    menu_home.setText(2, (char*)"Einst");
    menu.init(&menu_home);
    menu.draw();
    s_menu = &menu;

    menu.log((char*)"HwModules initialized");

    // initialize memory (includes data migration)
    memory.init(hwModules.getEeprom());

    if (memory.hasMigrated()) {
        char migMsg[22];
        sprintf(migMsg, "Mem. migrated to v%d", memory.getDataVersion());
        menu.log(migMsg);
    }

    menu.log((char*)"Memory initialized");

    enable_adc(adc_buffer);
    menu.log((char*)"ADC enabled");

    hwModules.setScheduler(&readerThread);
    menu.log((char*)"ReaderThread configured.");
    readerThread.start(NORMALPRIO);
    menu.log((char*)"ReaderThread started.");

    uint8_t mac[] = {
        LWIP_ETHADDR_0,
        LWIP_ETHADDR_1,
        LWIP_ETHADDR_2,
        LWIP_ETHADDR_3,
        LWIP_ETHADDR_4,
        LWIP_ETHADDR_5
    };

    net_opts.macaddress = &mac[0];
    net_opts.address = memory.getIpAddress();
    net_opts.gateway = (net_opts.address & 0x00FFFFFF) | (0xFE << 24); // xxx.xxx.xxx.254
    net_opts.netmask = 0x00FFFFFF; // 255.255.255.0

    char ipmsg[20];
    sprintf(
        ipmsg,
        "IP: %d.%d.%d.%d",
        (uint8_t)(net_opts.address & 0xff),
        (uint8_t)((net_opts.address >> 8)  & 0xFF),
        (uint8_t)((net_opts.address >> 16) & 0xFF),
        (uint8_t)((net_opts.address >> 24) & 0xFF)
    );
    menu.log(ipmsg);

    // Creates the LWIP threads (it changes priority internally)
    chThdCreateStatic(wa_lwip_thread, LWIP_THREAD_STACK_SIZE, NORMALPRIO + 1,lwip_thread, &net_opts);

    // Creates the HTTP thread (it changes priority internally).
    webServerThread.start(NORMALPRIO);

    menu.log((char*)"Network initialized.");
    chThdSleepMilliseconds(500);

    // ---------------------------------------------------------------------------

    channelX.begin(adc_buffer, 1, ADC3_CH_NUM, ADC3_SMP_DEPTH, false);
    channelY.begin(adc_buffer, 2, ADC3_CH_NUM, ADC3_SMP_DEPTH, false);
    channelZ.begin(adc_buffer, 3, ADC3_CH_NUM, ADC3_SMP_DEPTH, false);

    camera.begin(&SD2, &channelX, &channelY, &channelZ);

    camera.setButton(PTZ_FOCUS_AUTO, hwModules.getBi8(3), 7);
    camera.setLed(PTZ_FOCUS_AUTO, hwModules.getBi8(3), 7);
    camera.setButton(PTZ_MEM_1, hwModules.getBi8(3), 5);
    camera.setLed(PTZ_MEM_1, hwModules.getBi8(3), 5);
    camera.setButton(PTZ_MEM_2, hwModules.getBi8(3), 6);
    camera.setLed(PTZ_MEM_2, hwModules.getBi8(3), 6);
    camera.setButton(PTZ_MEM_3, hwModules.getBi8(3), 3);
    camera.setLed(PTZ_MEM_3, hwModules.getBi8(3), 3);
    camera.setButton(PTZ_MEM_4, hwModules.getBi8(3), 8);
    camera.setLed(PTZ_MEM_4, hwModules.getBi8(3), 8);
    camera.setButton(PTZ_MEM_Store, hwModules.getBi8(3), 4);
    camera.setLed(PTZ_MEM_Store, hwModules.getBi8(3), 4);

    menu.log((char*)"Camera configured");

    // ---------------------------------------------------------------------------

    ip_addr_t addr_proj_li;
    ip_addr_t addr_proj_re;
    ip_addr_t addr_klSaal_li;
    ip_addr_t addr_klSaal_re;
    ip_addr_t addr_stage;
    uint16_t port_proj = 5000;
    IP4_ADDR(&addr_proj_li, 192, 168, 40, 33);
    IP4_ADDR(& addr_proj_re, 192, 168, 40, 32);
    IP4_ADDR(&addr_klSaal_li, 192, 168, 40, 35);
    IP4_ADDR(&addr_klSaal_re, 192, 168, 40, 36);
    IP4_ADDR(&addr_stage, 192, 168, 40, 34);

//*
    displays.begin(
            addr_proj_li, port_proj,
            addr_proj_re, port_proj,
            addr_klSaal_li, port_proj,
            addr_klSaal_re, port_proj,
            addr_stage, port_proj,
            hwModules.getBi8(0),
            hwModules.getDisplay(), DISP_PROJ_EN_BUTTON);
//*/

    // ---------------------------------------------------------------------------

    ip_addr_t addr_hdmi_switch;
    ip_addr_t addr_scaler;
    IP4_ADDR(&addr_hdmi_switch, 192, 168, 40, 31);
    IP4_ADDR(&addr_scaler, 192, 168, 40, 31);

//*
    scalerAndSwitch.begin(
            addr_hdmi_switch, 101,
            addr_scaler, 102,
            hwModules.getBi8(4));
//*/

    // ---------------------------------------------------------------------------

    ip_addr_t matrix_ip_addr;
    IP4_ADDR(&matrix_ip_addr, 192, 168, 40, 31);

    matrix.begin(matrix_ip_addr, 100);

    SkaarhojBI8* current_bi8;

    current_bi8 = hwModules.getBi8(1);
    matrix.setButton(1, 1, current_bi8, 4);
    matrix.setButton(2, 1, current_bi8, 3);
    matrix.setButton(3, 1, current_bi8, 2);
    matrix.setButton(4, 1, current_bi8, 1);
    matrix.setButton(1, 2, current_bi8, 8);
    matrix.setButton(2, 2, current_bi8, 7);
    matrix.setButton(3, 2, current_bi8, 6);
    matrix.setButton(4, 2, current_bi8, 5);
    current_bi8 = hwModules.getBi8(2);
    matrix.setButton(1, 3, current_bi8, 4);
    matrix.setButton(2, 3, current_bi8, 3);
    matrix.setButton(3, 3, current_bi8, 2);
    matrix.setButton(4, 3, current_bi8, 1);
    matrix.setButton(1, 4, current_bi8, 8);
    matrix.setButton(2, 4, current_bi8, 7);
    matrix.setButton(3, 4, current_bi8, 6);
    matrix.setButton(4, 4, current_bi8, 5);

    menu.log((char*)"Matrix configured");

    // ---------------------------------------------------------------------------

    ip_addr_t atem_ip_addr;
    IP4_ADDR(&atem_ip_addr, 192, 168, 40, 21);

    channelFader.begin(adc_buffer, 0, ADC3_CH_NUM, ADC3_SMP_DEPTH, false);

    // Initialize LED controller.
    LedController* ledCtrl = hwModules.getLedCtrl();
    for (uint8_t i = 0; i < 16; i++) {
        ledCtrl->writeLed(i, 0);
    }

    menu.log((char*)"ATEM init...");
    atem.begin(atem_ip_addr, &channelFader, ledCtrl);

    // init button mapper
    mapper.begin(
        &memory,
        hwModules.getBi8(5),
        hwModules.getBi8(6)
    );

    // load mapping 0 and apply to video switcher
    mapper.load(0);
    mapper.apply(&atem);
    atem.setButton(ATEM_Cut, hwModules.getBi8(3), 1);
    atem.setLed(ATEM_Cut, hwModules.getBi8(3), 1);
    atem.setButton(ATEM_Auto, hwModules.getBi8(3), 2);
    atem.setLed(ATEM_Auto, hwModules.getBi8(3), 2);
    menu.log((char*)"ATEM Buttons mapped.");

    atem.deactivate();

    Display* display = hwModules.getDisplay();
    uint8_t blink_count = 0;

    // ----- ----- ----- ----- ----- ----- ----- ----- ----- -----

    menu.log((char*)"Performing tests...");

    char buttonColor[6] = {BI8_COLOR_OFF,BI8_COLOR_ON,BI8_COLOR_RED,BI8_COLOR_GREEN,BI8_COLOR_YELLOW,BI8_COLOR_BACKLIGHT};

    for (int i = 0; i < 6; i++) {
        for (int j = 0; j < 7; j++) {
            for (int k = 0; k <= NUMBER_BI8; k++) {
                hwModules.getBi8(j)->setButtonColor(k + 1, buttonColor[i]);
            }
        }
        chThdSleepMilliseconds(200);
    }

    menu.log((char*)"Tests performed");

    //
    // Everything is initialized -> start blink handling
    blink_enable = true;

    menu.log((char*)"Starting run loop...");

    // ----- ----- ----- ----- ----- ----- ----- ----- ----- -----
    // Main Loop.

    bool atem_online = false;
    menu.log((char*)"ATEM offline.");

    // sleep 1s till connect
    chThdSleepMilliseconds(1000);

    atem.connect();
    s_atem = &atem; // start run loop

    // create atem/camera run thread
    chThdCreateStatic(waTimeCriticalThread, sizeof(waTimeCriticalThread), NORMALPRIO, TimeCriticalThread, NULL);

    while (TRUE) {

        matrix.run();
        scalerAndSwitch.run();
        displays.run();

        bool online_temp = atem.online();
        if (atem_online != online_temp) {
            if (atem_online) {
                menu.log((char*)"ATEM offline.");
            } else {
                menu.log((char*)"ATEM online.");
            }
            atem_online = online_temp;
        }

        // Forward menu/display actions.
        for (uint8_t i = 0; i < 4; i++) {
            if (display->buttonUp(i)) {
                menu.buttonDown(i);
            }
        }
        menu.rotaryChange(MENU_ROT_0, display->getEncoder1(true));
        menu.rotaryChange(MENU_ROT_1, display->getEncoder2(true));

        menu.draw();

        blink_count++;

        if (blink_count == 200) {
            if (atem_online) {
                // adjust TvOne Scaler video format to ATEM video format
                scalerAndSwitch.setFormatFromAtem(atem.getVideoFormat());
            }

            blink_count = 0;
        }

        chThdSleepMilliseconds(5);
    }
}

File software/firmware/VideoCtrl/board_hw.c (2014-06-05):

/*
 * board_hw.c
 *
 *  Created on: 28.10.2013
 *      Author: Peter Schuster
 */

#include "board_hw.h"
#include "debugger.h"

I2CConfig i2c_1_conf;
I2CConfig i2c_2_conf;

SPIConfig spi_1_conf;

static adcsample_t* global_adc_buffer;

/*
 * ADC streaming callback.
 */
size_t adc3_samples_count = 0;
static void adc_cb(ADCDriver *adcp, adcsample_t *buffer, size_t n) {

  (void)adcp;
  if (global_adc_buffer == buffer) {
      adc3_samples_count = n;
  } else {
      adc3_samples_count += n;
  }
}

static void adc_error_cb(ADCDriver *adcp, adcerror_t err) {

  (void)adcp;
  (void)err;
}

/*
 * ADC conversion group.
 * Mode:        Continuous, 16 samples of 8 channels, SW triggered.
 * Channels:    IN11, IN12, IN11, IN12, IN11, IN12, Sensor, VRef.
 */
static const ADCConversionGroup adcgrp_conf3 = {
  TRUE,                         // Enables the circular buffer mode for the group.
  ADC3_CH_NUM,                  // Number of the analog channels belonging to the conversion group.
  adc_cb,                       // Callback function associated to the group or @p NULL.
  adc_error_cb,                 // Error callback or @p NULL.
  0,                            // CR1
  ADC_CR2_SWSTART,              // CR2
  0,                            // SMPR1 - In this field must be specified the sample times for channels 10...18.
  ADC_SMPR2_SMP_AN4(ADC_SAMPLE_56)
   | ADC_SMPR2_SMP_AN5(ADC_SAMPLE_56)
   | ADC_SMPR2_SMP_AN6(ADC_SAMPLE_56)
   | ADC_SMPR2_SMP_AN7(ADC_SAMPLE_56),  // SMPR2 - In this field must be specified the sample times for channels 0...9.
  ADC_SQR1_NUM_CH(ADC3_CH_NUM), // Conversion group sequence 13...16 + sequence length.
  0,                            // Conversion group sequence 7...12.
  ADC_SQR3_SQ1_N(ADC_CHANNEL_IN4)
   | ADC_SQR3_SQ2_N(ADC_CHANNEL_IN5)
   | ADC_SQR3_SQ3_N(ADC_CHANNEL_IN6)
   | ADC_SQR3_SQ4_N(ADC_CHANNEL_IN7)   // Conversion group sequence 1...6.
};

#if VISCA_UART
/*
 * This callback is invoked when a transmission buffer has been completely
 * read by the driver.
 */
static void uart2_tx_end(UARTDriver *uartp) {
    (void)uartp;
    // TODO?
}

/*
 * This callback is invoked when a transmission has physically completed.
 */
static void uart2_tx_end_physical(UARTDriver *uartp) {
    (void)uartp;
    // TODO?
}

/*
 * This callback is invoked when a receive buffer has been completely written.
 */
static void uart2_rx_buffer_filled(UARTDriver *uartp) {
    (void)uartp;
    // TODO?
}

/*
 * This callback is invoked when a character is received but the application
 * was not ready to receive it, the character is passed as parameter.
 */
static void uart2_char_rx(UARTDriver *uartp, uint16_t c) {
    (void)uartp;
    (void)c;
    // TODO?
}

/*
 * This callback is invoked on a receive error, the errors mask is passed
 * as parameter.
 */
void uart2_rx_error(UARTDriver *uartp, uartflags_t e) {
    (void)uartp;
    (void)e;
    // TODO?
}

/*
 * UART 2 driver configuration structure.
 */
static UARTConfig uart_conf2 = {
  uart2_tx_end,
  uart2_tx_end_physical,
  uart2_rx_buffer_filled,
  uart2_char_rx,
  uart2_rx_error,
  9600,            // speed
  0,                // CR1
  USART_CR2_STOP1_BITS | USART_CR2_LINEN,  // CR2
  0                 // CR3
};

#else // -> !VISCA_UART
   SerialConfig sd_2_conf;
#endif // end VISCA_UART

#ifdef LWIP_DEBUG
SerialConfig sd_3_conf;
#endif
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

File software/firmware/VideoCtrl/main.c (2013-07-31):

/*
    ChibiOS/RT - Copyright (C) 2006-2013 Giovanni Di Sirio

    Licensed under the Apache License, Version 2.0 (the "License");
    you may not use this file except in compliance with the License.
    You may obtain a copy of the License at

        http://www.apache.org/licenses/LICENSE-2.0

    Unless required by applicable law or agreed to in writing, software
    distributed under the License is distributed on an "AS IS" BASIS,
    WITHOUT WARRANTIES OR CONDITIONS OF ANY KIND, either express or implied.
    See the License for the specific language governing permissions and
    limitations under the License.
*/

#include "ch.h"
#include "hal.h"
#include "lwip/init.h"

#include "lwipthread.h"
#include "lwip/ip_addr.h"

#include "web/web.h"

/*
 * Green LED blinker thread, times are in milliseconds.
 */
static WORKING_AREA(waThread1, 128);
static msg_t Thread1(void *arg) {

  (void)arg;
  chRegSetThreadName("blinker");
  while (TRUE) {
    palClearPad(GPIOC, GPIOC_LED);
    chThdSleepMilliseconds(500);
    palSetPad(GPIOC, GPIOC_LED);
    chThdSleepMilliseconds(500);
  }

  return 0;
}

/*
 * Application entry point.
 */
int main(void) {

  /*
   * System initializations.
   * - HAL initialization, this also initializes the configured device drivers
   *   and performs the board-specific initializations.
   * - Kernel initialization, the main() function becomes a thread and the
   *   RTOS is active.
   */
  halInit();
  chSysInit();
//  lwip_init();


  /*
   * Activates the serial driver 6 using the driver default configuration.
   */
  sdStart(&SD6, NULL);

  /*
   * Creates the blinker thread.
   */
  chThdCreateStatic(waThread1, sizeof(waThread1), NORMALPRIO, Thread1, NULL);


  /*
   * Creates the LWIP threads (it changes priority internally).
   */
  chThdCreateStatic(wa_lwip_thread, LWIP_THREAD_STACK_SIZE, NORMALPRIO + 1,
                    lwip_thread, NULL);

  /*
   * Creates the HTTP thread (it changes priority internally).
   */
  chThdCreateStatic(wa_http_server, sizeof(wa_http_server), NORMALPRIO + 1,
                    http_server, NULL);

  /*
   * Normal main() thread activity, in this demo it does nothing except
   * sleeping in a loop and check the button state.
   */
  while (TRUE) {
    if (palReadPad(GPIOA, GPIOA_BUTTON_WKUP) == 0) {

    }

    chThdSleepMilliseconds(500);
  }
}

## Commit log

2013-05-01 Eagle files.
    [1456RH3.dwg, 1456RH3.igs, 1456RH3.stp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]
2013-05-15 Ordered Version
    Small mechanical changes
    [DisplayBoad.brd, DisplayBoad.sch, Linear Slider.brd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]
2013-06-05 Breakout Board v1
    [breakout.brd, breakout.sch]
2013-06-05 Push Button Dummy Board
    [PushButtonDummy.brd, PushButtonDummy.sch]
2013-07-31 Ordered breakout borad
    [breakout.brd]
2013-07-31 Changes to CAD file
    [Pultübersicht.dwg]
2013-07-31 First firmware draft
    [project.cfg]
2013-08-01 Switch to C++
2013-09-05 Added control for matrix switches
2013-10-08 I2C start
2013-10-09 i2c debugging
2013-10-10 Minimal i2c program
2013-10-14 Further I2C testing
2013-10-14 Breakout board fixes
    Pullups for I2C2, power cycle external boards.
    [breakout.brd, breakout.sch]
2013-10-14 Pull-up for SPI2 MOSI (see UEXT on mainboard)
    [breakout.brd, breakout.sch]
2013-10-14 Hack for BI8 boards.
2013-10-14 Full integration of BI8 boards.
2013-10-28 Initialize all hw drivers
2013-10-29 DisplayBoard: missing connections
    Design error: missing pwr connections for display backlight.
    [DisplayBoad.brd, DisplayBoad.sch]
2013-10-30 Small change to front layout.
    [Pultübersicht.dwg]
2013-10-30 Change SPI bus clk to 7 MHz.
2013-11-05 Fix: correct port for NSS
    [board_hw.c]
2013-11-05 Remove obsolete Wire.h/cpp
2013-11-11 Upgrade chibios
    I2C 10-bit drivers are now part of the official branch.
2013-11-11 Memory access
    [Memory.xlsx]
2013-11-13 ADC in 'continous' mode
2013-11-13 Abstract button functionallity
2013-11-13 Implemented display buttons.
2013-11-13 Thread for reading button status
2013-11-13 Use async ADC
2013-11-13 I2C mutual exclusion
2013-11-13 I2C: SCL at 400 kHz
2013-11-18 Encoder implementation
2013-12-19 Use UART driver for port 'usart2'.
2013-12-19 Encoder test sequence.
2013-12-19 Adapted enclosure to new layout and CAD version.
2013-12-25 First implementation of app for ATEM switcher
2013-12-27 Store-, load- and apply button mappings
    [Memory.xlsx]
2014-01-04 Enclosure finish
    [Back.dxf, Top.dxf]
2014-01-11 Docs for new boards and RM
2014-01-11 Switch USART2 vs. SERIAL2
2014-01-18 Ordered version of enclosure.
2014-01-30 Display changes
    begin() method,
    swap encoder A, B
2014-01-30 shift button mapping to second page
2014-01-30 Set initial button mapping on migration
2014-01-30 Registry for extenal HW-boards, track online status
2014-01-30 Memory layout doc
    [Memory.xlsx]
2014-01-30 Pseudo randomize pwm distrubution
2014-01-30 Docu for app-level video switcher and button mappings.
2014-01-30 Initialize all 4 mapping slots.
2014-02-02 Split ADC initialization
2014-02-09 Added button numbers in doc
2014-02-09 Fixes for video switcher (ATEM)
    [Videoswitcher.cpp, Videoswitcher.h]
2014-02-09 Fixes/changes to main app
    [main.cpp]
2014-03-15 PTZ Camera
2014-04-02 Reduce led backlight
2014-04-04 Added HDMI switch lib (ATEN 4 port)
2014-04-04 Implementation of Switcher-and-Scaler-App/Module
2014-04-05 Fix led handler for Projector/TV module
2014-04-05 Shift time critical stuff (-> non-tcp) to separate thread
2014-04-05 Fix TcpSerialAdapter (experimental)
    Note: this solution currently leads to high latencies (100 ms tcp
    receive timeout)
    [lwipopts.h]
2014-05-31 Button fix: don't query all buttons in main.
    [main.cpp]
2014-06-05 Update memory doc
    [Memory.xlsx]
2014-06-06 Fix hdmi switch
2014-06-21 Arduino millis()
2014-06-22 Reset video mute on device OFF
2014-06-22 ADC: average using 8 samples
2014-10-04 Fix TV control
    ref issue #6
    [main.cpp]
2014-10-07 Run offset + SplitExecuter
    Run offset for different TVs and "SplitTvExecuter" ensuring consistent
    state for devices controlled by a single button / led.
    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
2014-10-10 Increase max TCP connections to 10
    required for issue #6
    [lwipopts.h]
2015-01-03 Handle pressed buttons only when "Proj. enable switch" is active.
    Closes task #12
2015-01-12 Several ATEM transition fixes
    see issue #5
    [Videoswitcher.cpp, Videoswitcher.h]
2015-01-12 PTZ camera refactoring
2015-01-13 New version of slider board
    Common anode, molex conn. (ordered)
    [Linear Slider.brd, Linear Slider.sch]
2015-02-08 Temporarily disable display buttons.
2015-02-08 Fix:/Check when Display buttons board/ic crashed
2015-04-03 Reverse output parsing
    To prefer longer string matches and 50 Hz formats.
2015-04-06 Fix: close pcb in invalid state.
2015-04-06 Track branch VideoCtrl.
2015-04-06 Menu system
    see issue #8
    [Display-PixelMapping.xlsx]

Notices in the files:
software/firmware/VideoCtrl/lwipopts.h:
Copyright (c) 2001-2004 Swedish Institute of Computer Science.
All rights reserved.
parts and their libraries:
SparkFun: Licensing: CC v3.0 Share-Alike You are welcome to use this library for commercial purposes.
